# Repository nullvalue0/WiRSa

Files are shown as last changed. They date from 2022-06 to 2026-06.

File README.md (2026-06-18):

# RetroDisks WiRSa v3 - WiFi RS232 Serial Modem Adapter

The WiRSa v3 is a WiFi-to-RS232 serial adapter designed for legacy computing systems. It allows vintage computers to connect to modern networks via WiFi, supporting telnet BBS connectivity, file transfers, and network gateway functionality.



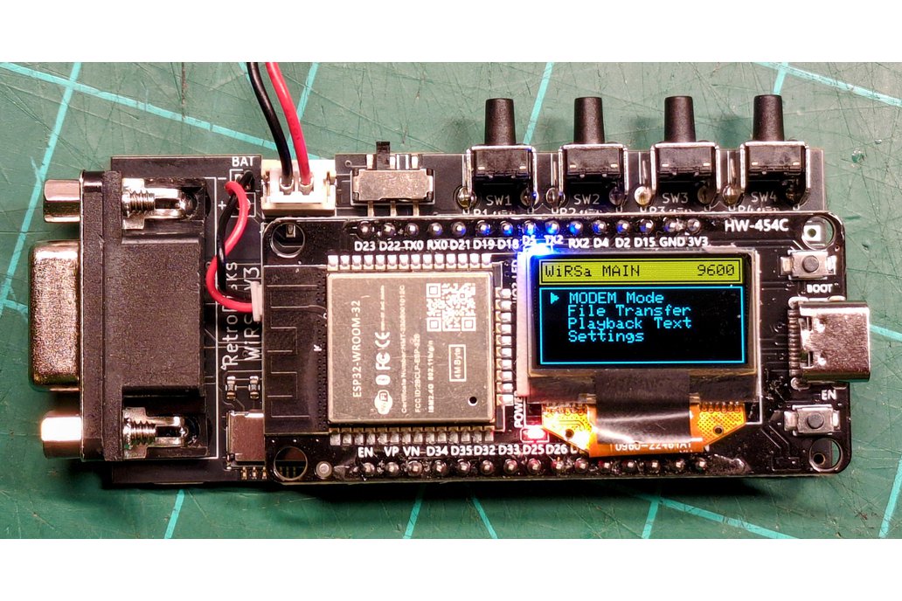
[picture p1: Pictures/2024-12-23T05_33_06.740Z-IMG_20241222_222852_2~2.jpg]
WiRSa Menu Action


## Kits & assembled units available for sale
If you prefer to save yourself some time, I have some units (fully assembled or kit) available for sale. I had quite a few PCB's made up and I am trying to keep these as cheap as possible. You can purchase on [SmallRun](https://smallrun.net/shop/retrodisks/wirsa-v3-wifi-rs232-serial-modem).
WiRSa v3 Wifi RS232 Serial Modem with SD Reader, SLIP, PPP, Telnet on SmallRun (https://smallrun.net/shop/retrodisks/wirsa-v3-wifi-rs232-serial-modem?ref=card)

## Features

### Hardware

- **Processor:** ESP-WROOM-32D with WiFi and Bluetooth 4.2 BLE
- **Display:** 128x64 two-color OLED display for settings, commands, and real-time data
- **Serial Port:** Female DB9 (DE9) connector
- **Full RS232 Breakout:**
  - DSR/DTR (Data Set Ready / Data Terminal Ready)
  - RTS/CTS (Request to Send / Clear to Send)
  - DCD (Data Carrier Detect)
  - RI (Ring Indicator)
- **Storage:** Built-in micro SD card reader for file transfers and text playback
- **Power:**
  - USB-C power connector
  - Optional 2000mAh 3.7V Li-Po battery (~14 hours runtime)
- **Navigation:** Four physical buttons for menu navigation

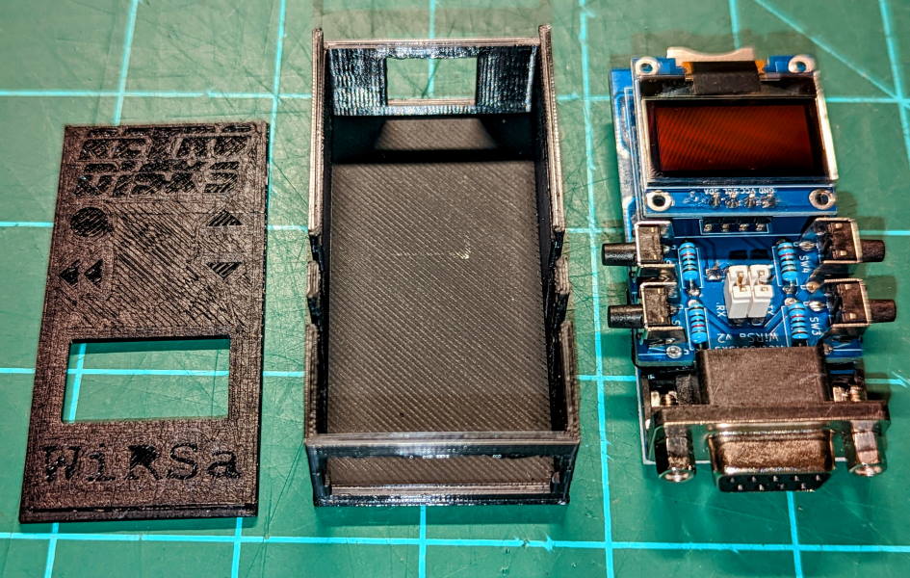
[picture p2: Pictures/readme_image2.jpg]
WiRSa Unboxing Action


### Operating Modes

1. **MODEM Mode** - Hayes-compatible AT command modem emulation for telnet/BBS connectivity
2. **Telnet Server** - Built-in telnet server allows for remote terminal access
3. **File Transfer** - Binary file transfer directly from SD card via XModem, YModem, and ZModem protocols
4. **Text Playback** - Display text files from SD card through the serial port
5. **PPP Gateway** - Point-to-Point Protocol gateway for TCP/IP networking
6. **SLIP Gateway** - Serial Line Internet Protocol gateway
7. **Utilities** - Diagnostics and troubleshooting tools including signal monitoring and loopback testing
8. **Config** - Settings for baud rate, serial configuration, display orientation, and more

### Software Features

- **AT Command Set** - Full Hayes-compatible modem commands
- **Web Interface** - Built-in web server for status monitoring, configuration and file management
- **Flow Control** - Hardware (RTS/CTS) and software (XON/XOFF) flow control
- **Speed Dial** - 10 programmable speed dial entries
- **PETSCII Translation** - Support for Commodore computers
- **Telnet Protocol** - Automatic Telnet IAC handling
- **OTA Updates** - Over-the-air firmware updates via HTTP

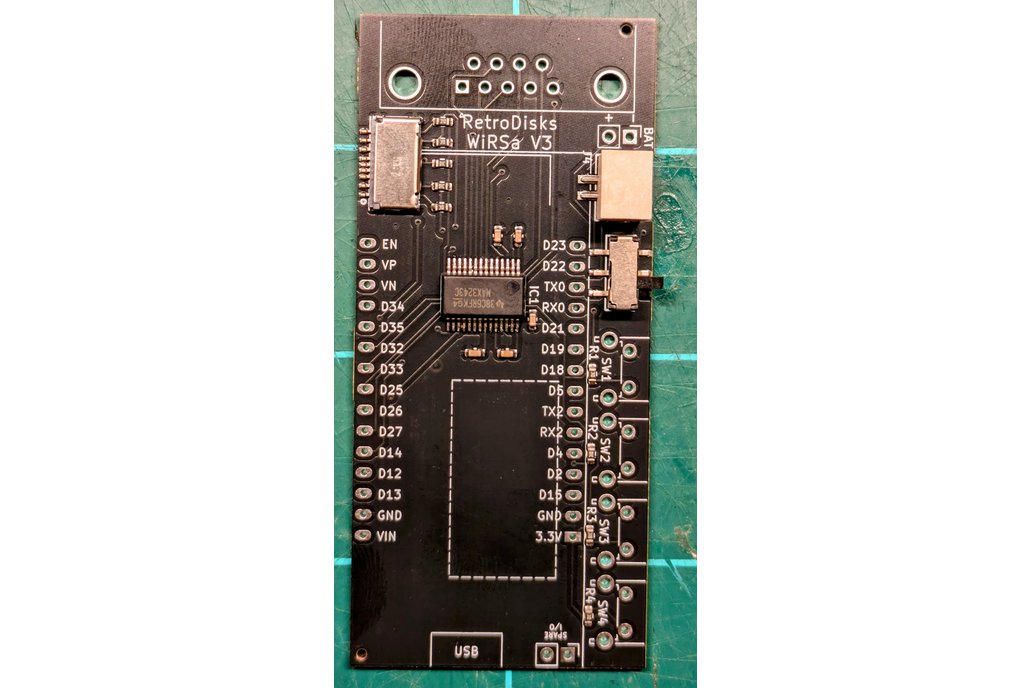
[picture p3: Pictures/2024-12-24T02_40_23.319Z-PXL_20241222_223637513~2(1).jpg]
WiRSa BBS Action


## Getting Started

### WiFi Configuration

1. Connect to your computer via serial port (default: 9600 baud, 8N1)
2. Enter your WiFi credentials using AT commands (2.4 GHz networks only):
   ```
   AT$SSID=YourNetworkName
   AT$PASS=YourPassword
   ```
3. Save settings: `AT&W`
4. Reboot or reconnect to apply

### Connecting to a BBS

Use the dial command with the host and port:
```
ATDT bbs.example.com:23
```

Or configure speed dial entries:
```
AT&Z0=bbs.example.com:23
ATDS0
```

### Useful AT Commands

| Command | Description |
|---|---|
| `AT` | Test connection (returns OK) |
| `ATDT<host:port>` | Dial/connect to TCP host |
| `ATDS<0-9>` | Speed dial entry |
| `ATH` | Hang up connection |
| `ATA` | Answer incoming connection |
| `ATO` | Return online from command mode |
| `+++` | Escape to command mode (during connection) |
| `ATE0/1` | Echo off/on |
| `ATV0/1` | Verbose results off/on |
| `ATI` | Display network info |
| `AT&V` | View current settings |
| `AT&W` | Save settings to EEPROM |
| `ATZ` | Load settings from EEPROM |
| `AT&F` | Restore factory defaults |
| `AT&K<0/1/2>` | Flow control (0=none, 1=hardware, 2=software) |
| `ATNET<0/1>` | Telnet protocol handling off/on |
| `ATPET=<0/1>` | PETSCII translation off/on |
| `AT$SSID=` | Set WiFi SSID |
| `AT$PASS=` | Set WiFi password |
| `AT$SP=<port>` | Set listening port |
| `ATS0=<0/1>` | Auto-answer off/on |
| `ATFC` | Check for firmware updates |
| `ATFU` | Perform firmware update |
| `AT?` or `ATHELP` | Display help |
| `ATX` | Exit MODEM Mode, return to WiRSa main menu |

## File Transfers

The WiRSa supports binary file transfers directly from the SD card using industry-standard protocols:

- **XModem** - Basic 128-byte block transfer with checksum
- **YModem** - Batch file transfer with filename and size
- **ZModem** - Streaming protocol with CRC16/CRC32 and automatic resume

To transfer files:
1. Insert SD card with files
2. Select "File Transfer" from the main menu
3. Choose the transfer protocol
4. Select send or receive
5. Initiate the transfer from your terminal software

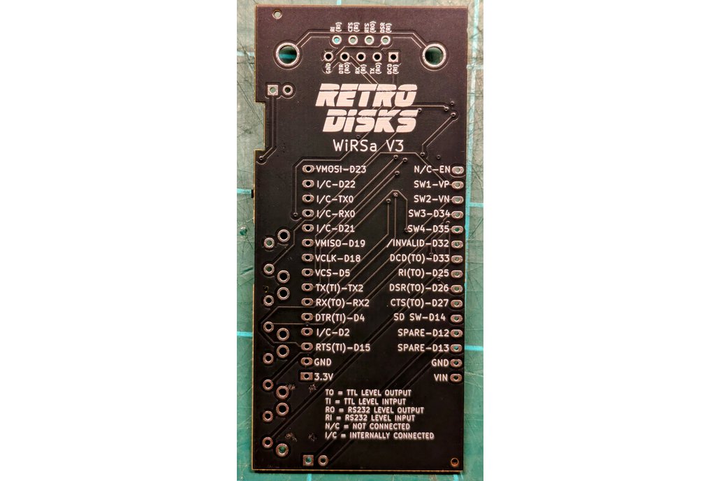
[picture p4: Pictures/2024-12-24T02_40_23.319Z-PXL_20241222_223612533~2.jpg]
WiRSa PCB Action


## SLIP / PPP Gateway Modes

The WiRSa provides full TCP/IP networking capabilities for vintage computers through two standard protocols: **SLIP** (Serial Line Internet Protocol) and **PPP** (Point-to-Point Protocol). These modes turn the WiRSa into a dial-up internet gateway, allowing retro systems to browse the web, use email clients, FTP, and access other network services.

### How It Works

Both modes operate as NAT (Network Address Translation) gateways:
1. The vintage computer connects via the serial port
2. The WiRSa performs NAT translation between the serial link and WiFi
3. Outbound traffic is routed to the internet via the ESP32's WiFi connection
4. The vintage computer appears to have full internet access

### SLIP Mode

SLIP is a simpler, older protocol with less overhead. It works well with:
- **DOS** with packet drivers (ETHERSLIP, SLIPPER, etc.)
- **Early Windows 3.x** with Trumpet Winsock
- **Classic Mac OS** with MacSLIP or InterSLIP
- **Linux** with `slattach`

**Default Configuration:**
- Gateway IP: 192.168.7.1 (WiRSa)
- Client IP: 192.168.7.2 (vintage computer)
- DNS: 8.8.8.8

### PPP Mode

PPP is more robust with built-in negotiation, authentication support, and error detection. It's the standard for:
- **Windows 95/98/ME** Dial-Up Networking
- **Windows 3.11** with Microsoft DUN
- **Mac OS 8/9** with PPP/Remote Access
- **Linux** with `pppd`

**Default Configuration:**
- Gateway IP: 192.168.8.1 (WiRSa)
- Client IP: 192.168.8.2 (assigned to client)
- Primary DNS: 8.8.8.8
- Secondary DNS: 8.8.4.4

### Entering SLIP/PPP Mode

**From the WiRSa Menu: (*if your host OS is expecting an "always on" connection*)**
1. Navigate to "PPP Gateway" or "SLIP Gateway" from the main menu
2. Select "Start Gateway"

**Using AT Dial Commands: (*must set the device to Modem Mode first*)**
```
ATDT SLIP      - Enter SLIP mode
ATDT 7547      - Enter SLIP mode (phone keypad for "SLIP")

ATDT PPP       - Enter PPP mode
ATDT 777       - Enter PPP mode (phone keypad for "PPP")
```

**Using AT Commands: (*must set the device to Modem Mode first*)**
```
AT$SLIP        - Enter SLIP mode directly
AT$PPP         - Enter PPP mode directly
```

### Port Forwarding

Port forwarding allows incoming connections from the internet to reach services running on your vintage computer. This is useful for:

- **Hosting a BBS** - Run a BBS on your vintage computer accessible from the internet
- **FTP Server** - Share files from your retro machine
- **Web Server** - Host a vintage web server (Windows 95 Personal Web Server, etc.)
- **Game Servers** - Host multiplayer games on classic systems
- **SSH/Telnet Access** - Remote into your vintage computer

**Configuring Port Forwards:**

From the menu:
1. Enter SLIP or PPP Gateway menu
2. Select "Port Forwards"
3. Choose "Add Forward"
4. Enter protocol (TCP/UDP), external port, internal IP, and internal port

Using AT commands:
```
AT$SLIPFWD=TCP,80,80      - Forward TCP port 80 to client port 80
AT$SLIPFWD=UDP,53,53      - Forward UDP port 53 (DNS)
AT$SLIPFWDDEL=0           - Remove forward at index 0

AT$PPPFWD=TCP,23,23       - Forward TCP port 23 (telnet)
AT$PPPFWD=TCP,21,21       - Forward TCP port 21 (FTP)
AT$PPPFWDDEL=0            - Remove forward at index 0
```

**Note:** Port forwards are shared between SLIP and PPP modes and persist across reboots.

### Setting Up SLIP Under DOS

**Requirements:**
- MS-DOS, DR-DOS, FreeDOS, etc
- A SLIP packet driver (ETHERSLIP, SLIPPER, or CSLIPPER)
- TCP/IP applications (mTCP suite, Arachne or MicroWeb browser, NCSA Telnet, etc.)

**Step 1: Configure WiRSa**
```
AT$SSID=YourWiFiNetwork
AT$PASS=YourPassword
AT&W
```

**Step 2: Install Packet Driver**

Create a batch file (e.g., `SLIP.BAT`):
```batch
@echo off
REM Load SLIP packet driver on COM1 at 115200 baud
ETHERSL 0x60 4 0x3F8 115200
REM Or for COM2: ETHERSL 0x60 3 0x2F8 115200
```

**Step 3: Configure TCP/IP Stack**

For mTCP, create `MTCP.CFG`:
```
PACKETINT 0x60
IPADDR 192.168.7.2
NETMASK 255.255.255.0
GATEWAY 192.168.7.1
NAMESERVER 8.8.8.8
```

Set environment variable:
```batch
SET MTCPCFG=C:\MTCP\MTCP.CFG
```

**Step 4: Connect**

On the WiRSa, start SLIP Gateway by enabling from the buttons/screen menu, from the serial menu (exit terminal after Starting Gateway, it starts immediately), or by dialing
```
ATDT SLIP
```

**Step 5: Test Connection**
```
PING 8.8.8.8
TELNET bbs.example.com
```

### Setting Up PPP Under Windows 95/98 Dial-Up Networking

**Step 1: Create a New Connection**
1. Open "My Computer" → "Dial-Up Networking"
2. Click "Make New Connection"
3. Name it "WiRSa Internet" (or any name)
4. Select your serial port modem (or "Standard Modem" on the COM port)
5. For phone number, enter: `PPP` (or `777`)

**Step 2: Configure the Connection**
1. Right-click the new connection → "Properties"
2. **General tab:** Ensure correct modem/port is selected
3. **Server Types tab:**
   - Type of Dial-Up Server: "PPP: Internet, Windows NT Server, Windows 98"
   - Uncheck "Log on to network" (unless needed)
   - Check "Enable software compression" (optional)
   - Check "TCP/IP" under Allowed network protocols
   - Uncheck NetBEUI and IPX/SPX unless needed
4. Click "TCP/IP Settings":
   - Select "Server assigned IP address"
   - Select "Server assigned name server addresses"
   - Click OK

**Step 3: Modem Settings**
1. Go to Control Panel → Modems → Properties
2. Set maximum speed to match WiRSa baud rate (115200 recommended, plus Flow Control enabled [AT&K1])
3. Under "Connection" tab, set 8 data bits, No parity, 1 stop bit
4. Make sure to put the WiRSa into Modem mode before proceeding

**Step 4: Connect**
1. Double-click the connection
2. Leave username/password blank (or enter any values - WiRSa ignores auth)
3. Click "Connect"
4. The WiRSa will respond "CONNECT PPP" and negotiate the link

**Step 5: Verify Connection**
- Open a command prompt: `ping 8.8.8.8`
- Open Internet Explorer and browse!

### Setting Up PPP Under Windows 3.11

**Requirements:**
- Windows 3.11 for Workgroups
- Microsoft TCP/IP-32 or Trumpet Winsock
- Dial-Up Networking 1.0 for Windows 3.11

**Step 1: Install TCP/IP-32**
1. Run Network Setup
2. Add "Microsoft TCP/IP-32"
3. Configure with DHCP or manual IP (the WiRSa will assign IPs)

**Step 2: Configure RAS (Remote Access Service)**
1. Install RAS if not present
2. Add your modem on the appropriate COM port
3. Create a new phonebook entry with phone number "PPP" or "777"

**Step 3: Connect**
1. Open Remote Access
2. Select your WiRSa entry
3. Make sure WiRSa is in Modem Mode
4. Click "Dial"

### Setting Up SLIP Under Linux

Linux has built-in SLIP support via the `slattach` utility. This guide covers configuring the serial port, enabling SLIP, and testing connectivity.

**Requirements:**
- Linux system with a physical serial port (directly connected to WiRSa)
- Root/sudo access
- `slattach` utility (usually included in `net-tools` or `slip` package)

**Step 1: Identify Your Serial Port**

First, identify the serial device. Physical serial ports are typically:
```bash
# First serial port (COM1 equivalent)
/dev/ttyS0

# Second serial port (COM2 equivalent)
/dev/ttyS1

# List available serial ports
ls -la /dev/ttyS*

# Check which serial ports are available
dmesg | grep -i ttyS
```

**Step 2: Configure the Serial Port**

Before starting SLIP, configure the serial port to match your WiRSa settings. Use `stty` to set the baud rate and other parameters:

```bash
# Set baud rate to 115200, 8N1, no flow control
sudo stty -F /dev/ttyS0 115200 cs8 -cstopb -parenb raw -echo

# For hardware flow control (if WiRSa has AT&K1 enabled), add crtscts:
sudo stty -F /dev/ttyS0 115200 cs8 -cstopb -parenb raw -echo crtscts

# Verify settings
stty -F /dev/ttyS0 -a
```

Key `stty` options:
| Option | Description |
|---|---|
| `115200` | Baud rate (match WiRSa setting) |
| `cs8` | 8 data bits |
| `-cstopb` | 1 stop bit (use `cstopb` for 2) |
| `-parenb` | No parity |
| `raw` | Raw mode (no input/output processing) |
| `-echo` | Disable local echo |
| `crtscts` | Enable hardware flow control |

**Step 3: Test Serial Communication**

Before enabling SLIP, verify you can communicate with the WiRSa:

```bash
# Open a simple terminal session
# Press Ctrl+C to exit when done
sudo cat /dev/ttyS0 &
echo "AT" | sudo tee /dev/ttyS0

# You should see "OK" response from WiRSa
# Kill the background cat process
kill %1

# Alternative: use screen or minicom
screen /dev/ttyS0 115200
# (Press Ctrl+A then K to exit screen)
```

**Step 4: Start SLIP Gateway on WiRSa**

From your terminal session with WiRSa, enter SLIP mode:
```
AT$SLIP
```
Or dial into SLIP mode:
```
ATDT SLIP
```

You should see "CONNECT SLIP" response. Now exit your terminal program (the serial port must be free for slattach).

**Step 5: Enable SLIP on Linux**

Attach the SLIP interface using `slattach`:

```bash
# Start slattach in the background
# -p slip = SLIP protocol
# -s 115200 = baud rate
sudo slattach -p slip -s 115200 /dev/ttyS0 &

# Note the PID for later cleanup
SLATTACH_PID=$!
```

**Step 6: Configure the Network Interface**

Once slattach is running, a `sl0` interface will be created. Configure it:

```bash
# Bring up the interface with the client IP
sudo ifconfig sl0 192.168.7.2 pointopoint 192.168.7.1 up

# Or using ip command (modern systems)
sudo ip addr add 192.168.7.2 peer 192.168.7.1 dev sl0
sudo ip link set sl0 up

# Add default route through the SLIP gateway (optional - routes all traffic through WiRSa)
sudo ip route add default via 192.168.7.1 dev sl0

# Or add only specific routes
sudo ip route add 8.8.8.8 via 192.168.7.1 dev sl0
```

**Step 7: Configure DNS**

Add the DNS server to your resolver configuration:

```bash
# Temporary - add to /etc/resolv.conf
echo "nameserver 8.8.8.8" | sudo tee -a /etc/resolv.conf

# For systems using systemd-resolved
sudo resolvectl dns sl0 8.8.8.8
```

**Step 8: Test the Connection**

Verify connectivity through the SLIP link:

```bash
# Ping the WiRSa gateway
ping -c 3 192.168.7.1

# Ping an external IP (Google DNS)
ping -c 3 8.8.8.8

# Test DNS resolution
ping -c 3 google.com

# Check routing
ip route show
```

Expected output for successful ping:
```
PING 192.168.7.1 (192.168.7.1) 56(84) bytes of data.
64 bytes from 192.168.7.1: icmp_seq=1 ttl=64 time=5.23 ms
64 bytes from 192.168.7.1: icmp_seq=2 ttl=64 time=4.89 ms
64 bytes from 192.168.7.1: icmp_seq=3 ttl=64 time=5.01 ms
```

**Step 9: Cleanup (When Done)**

To disconnect and clean up:

```bash
# Bring down the interface
sudo ip link set sl0 down

# Kill slattach
sudo kill $SLATTACH_PID
# Or find and kill by name
sudo killall slattach
```

**Complete Setup Script**

Here's a complete script to automate the Linux SLIP setup:

```bash
#!/bin/bash
# slip-connect.sh - Connect to WiRSa via SLIP

DEVICE="/dev/ttyS0"
BAUD="115200"
LOCAL_IP="192.168.7.2"
GATEWAY_IP="192.168.7.1"
DNS="8.8.8.8"

# Configure serial port
sudo stty -F $DEVICE $BAUD cs8 -cstopb -parenb raw -echo

# Start slattach
sudo slattach -p slip -s $BAUD $DEVICE &
sleep 2

# Configure interface
sudo ip addr add $LOCAL_IP peer $GATEWAY_IP dev sl0
sudo ip link set sl0 up

# Add route for external traffic
sudo ip route add default via $GATEWAY_IP dev sl0

# Configure DNS
sudo resolvectl dns sl0 $DNS 2>/dev/null || echo "nameserver $DNS" | sudo tee /etc/resolv.conf

echo "SLIP connection established"
echo "  Local IP:  $LOCAL_IP"
echo "  Gateway:   $GATEWAY_IP"
echo "  DNS:       $DNS"
echo ""
echo "Test with: ping 8.8.8.8"
```

**Troubleshooting**

| Issue | Solution |
|---|---|
| "Device or resource busy" | Another program is using the serial port. Close any terminal emulators. |
| No sl0 interface appears | Check if slattach is running: `ps aux \| grep slattach`. Verify WiRSa is in SLIP mode. |
| Ping to gateway fails | Verify serial settings match WiRSa. Check cable connections. |
| External pings fail | Ensure WiRSa has WiFi connectivity. Check `AT$SLIPSTAT` for packet statistics. |
| Permission denied | Use sudo or add your user to the `dialout` group: `sudo usermod -aG dialout $USER` |
| Serial port not found | Ensure the serial port is enabled in BIOS/UEFI. Check `setserial -g /dev/ttyS*` for port status. |

### Configuration AT Commands

**SLIP Configuration:**
| Command | Description |
|---|---|
| `AT$SLIP` | Enter SLIP gateway mode |
| `AT$SLIPIP=x.x.x.x` | Set gateway IP address |
| `AT$SLIPCLIENT=x.x.x.x` | Set client IP address |
| `AT$SLIPDNS=x.x.x.x` | Set DNS server |
| `AT$SLIPSHOW` | Show current SLIP configuration |
| `AT$SLIPSTAT` | Show SLIP statistics |
| `AT$SLIPFWD=proto,ext,int` | Add port forward |
| `AT$SLIPFWDDEL=index` | Remove port forward |

**PPP Configuration:**
| Command | Description |
|---|---|
| `AT$PPP` | Enter PPP gateway mode |
| `AT$PPPGW=x.x.x.x` | Set gateway IP address |
| `AT$PPPPOOL=x.x.x.x` | Set client pool start IP |
| `AT$PPPDNS=x.x.x.x` | Set primary DNS server |
| `AT$PPPDNS2=x.x.x.x` | Set secondary DNS server |
| `AT$PPPSHOW` | Show current PPP configuration |
| `AT$PPPSTAT` | Show PPP statistics |
| `AT$PPPFWD=proto,ext,int` | Add port forward |
| `AT$PPPFWDDEL=index` | Remove port forward |
| `AT$PPPFWDLIST` | List all port forwards |

### Exiting SLIP/PPP Mode

- Press the **BACK button** on the WiRSa
- Send `+++` escape sequence (USB serial only in SLIP mode)
- Disconnect from the client side (PPP will detect link termination)

## Telnet Server Mode

The WiRSa includes a built-in Telnet server that allows remote access to devices connected via the serial port. This is useful for:

- **Vintage terminals and computers** - Access systems that originally connected to serial terminals (mainframes, minicomputers, Unix systems)
- **Serial console access** - Remotely manage routers, switches, or embedded devices with serial management ports
- **Headless systems** - Access single-board computers or systems without displays
- **BBS hosting** - Run a BBS on a vintage computer and accept telnet connections

### How It Works

1. The WiRSa listens for incoming TCP connections on a configurable port (default: 23)
2. When a connection is made, data is bridged bidirectionally between the telnet client and the serial port
3. The remote user interacts with whatever is connected to the WiRSa's serial port as if they were locally connected

### Configuration

**Set the listening port:**
```
AT$SP=23        - Set server port to 23 (default telnet port)
AT$SP=2323      - Use alternate port 2323
AT$SP?          - Query current port
```

**Configure auto-answer:**
```
ATS0=1          - Enable auto-answer (automatically connect incoming calls)
ATS0=0          - Disable auto-answer (ring and wait for manual answer)
ATS0?           - Query current setting
```

**Telnet protocol handling:**
```
ATNET1          - Enable telnet IAC sequence handling (recommended for telnet clients)
ATNET0          - Disable telnet handling (raw TCP mode)
ATNET?          - Query current setting
```

### Connecting to the WiRSa

From any computer on the same network:
```bash
telnet <wirsa-ip-address> 23
```

Or with a custom port:
```bash
telnet <wirsa-ip-address> 2323
```

### Console Mode vs Call Mode

The WiRSa supports two types of incoming connections:

**Console Connection (First Connection):**
- The first telnet connection becomes a "console" session
- Stays in AT command mode - you can type AT commands
- Use `ATDT <host:port>` to dial out to BBSes
- Full modem emulation available

**Call Connection (With Auto-Answer):**
- When `ATS0=1` is set, subsequent connections bridge directly to serial
- Data passes transparently between telnet and serial
- Use `+++` to escape back to command mode
- Use `ATH` to hang up

### Example: Remote Terminal Access

**Scenario:** You have a vintage Unix system with a serial console, and you want to access it remotely via telnet.

1. Connect the WiRSa to the Unix system's serial port
2. Configure WiRSa to match the system's serial settings:
   ```
   AT$SB=9600      - Set baud rate (match your system)
   ATS0=1          - Enable auto-answer
   ATNET1          - Enable telnet handling
   AT&W            - Save settings
   ```
3. From a remote computer, telnet to the WiRSa's IP address
4. You'll be connected directly to the Unix system's serial console

### Example: Hosting a BBS

**Scenario:** Run a BBS on a vintage computer and accept incoming telnet connections.

1. Connect WiRSa to the vintage computer running BBS software
2. Configure WiRSa:
   ```
   AT$SP=23        - Listen on port 23
   ATS0=1          - Auto-answer incoming connections
   ATNET1          - Handle telnet protocol
   AT&W            - Save settings
   ```
3. Configure your router to forward port 23 to the WiRSa's IP address
4. Users can now telnet to your public IP to access the BBS

### Manual Answer Mode

When auto-answer is disabled (`ATS0=0`), incoming connections trigger a "RING" message:

```
RING
RING
RING
```

To answer manually, type:
```
ATA             - Answer the incoming call
```

This is useful when you want to screen incoming connections or when the connected device needs preparation before accepting a connection.

## Diagnostics

The Utilities menu provides diagnostic tools for troubleshooting:

- **Signal Monitor** - Real-time display of RS232 signal states (DCD, RTS, CTS, DTR, DSR, RI)
- **Loopback Test** - Test serial communication integrity
- **Statistics** - View connection counts and byte transfer statistics

## Hardware Connections

### Pin Assignments

| Function | GPIO | Description |
|---|---|---|
| RXD2 | 16 | UART2 RX (from computer) |
| TXD2 | 17 | UART2 TX (to computer) |
| DCD | 33 | Data Carrier Detect (output) |
| RTS | 15 | Request to Send (output) |
| CTS | 27 | Clear to Send (input) |
| DTR | 4 | Data Terminal Ready |
| DSR | 26 | Data Set Ready |
| RI | 25 | Ring Indicator |
| SD CS | 5 | SD Card Chip Select |
| SD MOSI | 23 | SD Card MOSI |
| SD MISO | 19 | SD Card MISO |
| SD SCK | 18 | SD Card Clock |

### Navigation Buttons

| Button | GPIO | Function |
|---|---|---|
| SW1 | 36 | DOWN |
| SW2 | 39 | BACK |
| SW3 | 34 | ENTER |
| SW4 | 35 | UP |

## Building the Firmware

This is a PlatformIO project. See [README-PLATFORMIO.md](README-PLATFORMIO.md) for detailed build instructions.

Quick start:
```bash
# Build firmware
platformio run

# Upload to ESP32
platformio run --target upload

# Monitor serial output
platformio device monitor
```

## Origin Story

The WiRSa originated as a film prop for Apple TV's "The Shining Girls," where it simulated realistic computer interaction by playing back pre-recorded text files while actors typed on vintage terminals.

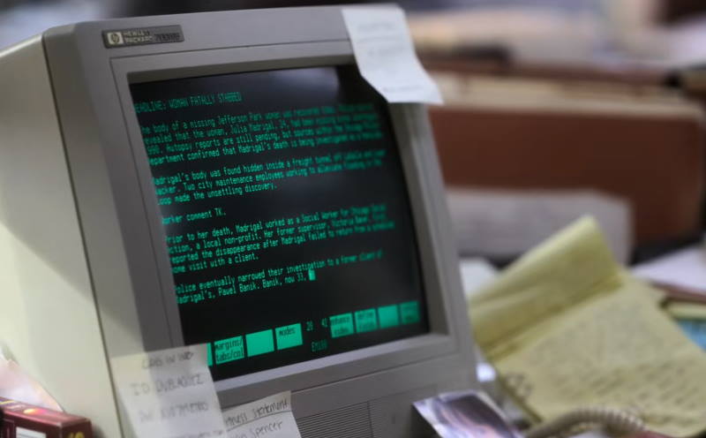
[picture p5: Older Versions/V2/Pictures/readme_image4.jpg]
WiRSa On Film


## Resources

- **Source Code:** Complete firmware, schematics (KiCAD), Gerber files, and enclosure designs (OpenSCAD) available in this repository
- **Contact:** nullvalue@gmail.com

## License

MIT License - See source code header for full license text.

Copyright (C) 2026 Aron Hoekstra

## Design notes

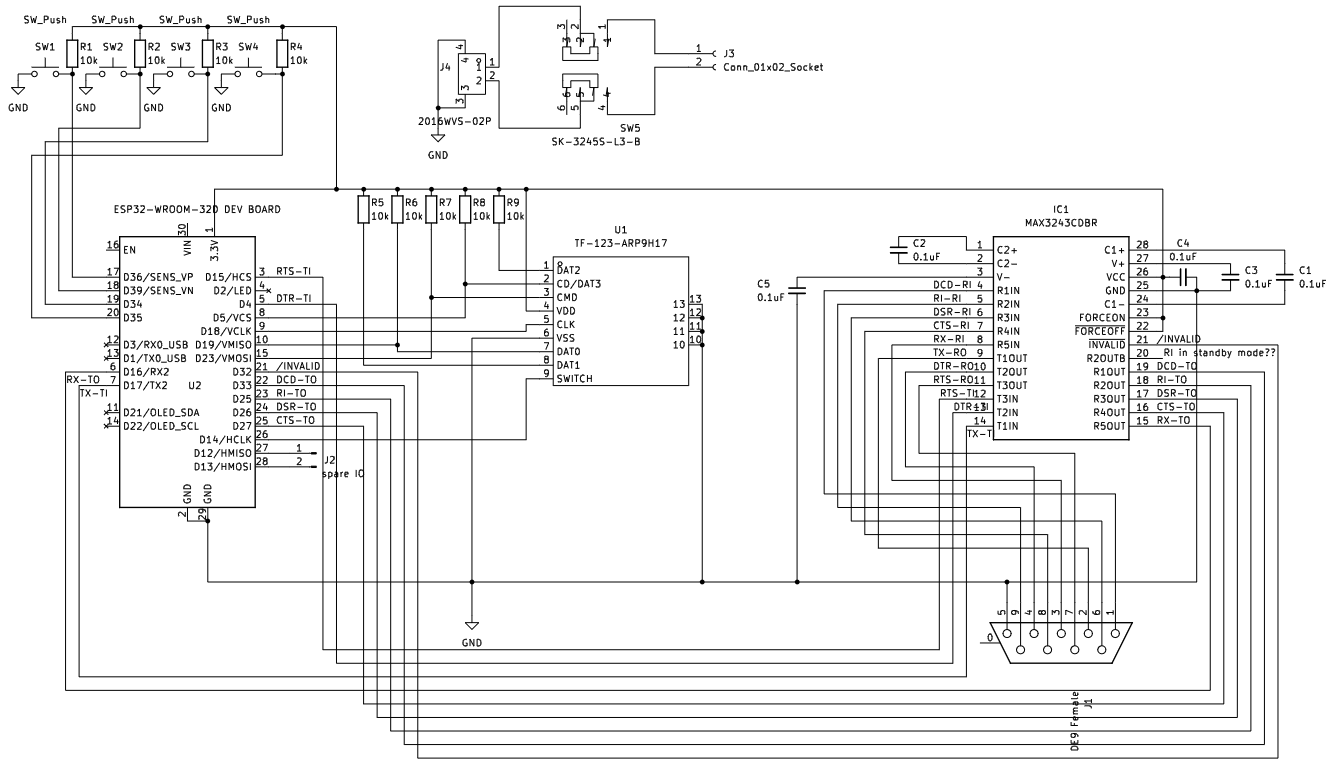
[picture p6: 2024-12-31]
PCB/WiRSa V3 Schematic.png

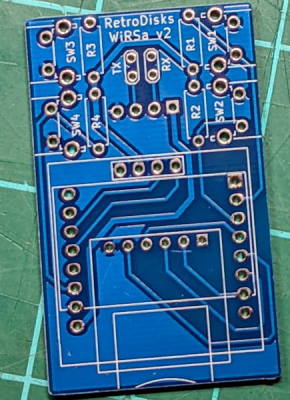
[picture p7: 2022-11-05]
Pictures/readme_image5.jpg

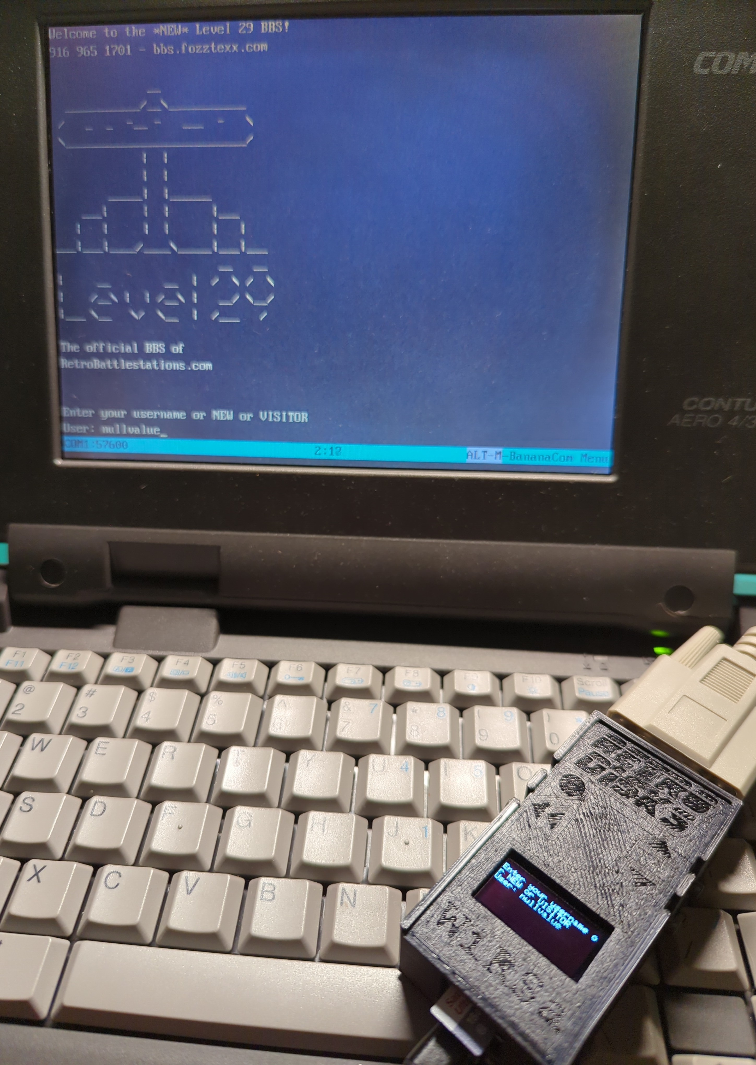
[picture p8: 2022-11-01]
Pictures/v2-IMG_20221031_160522~2 (6).jpg

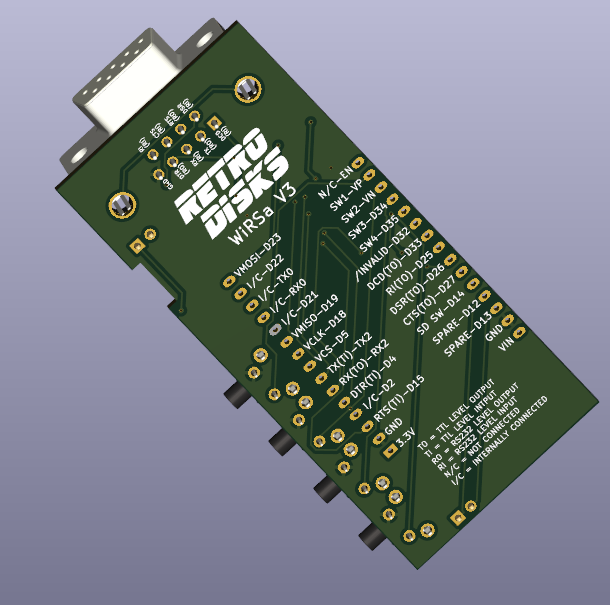
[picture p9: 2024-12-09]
Pictures/v3render1.png

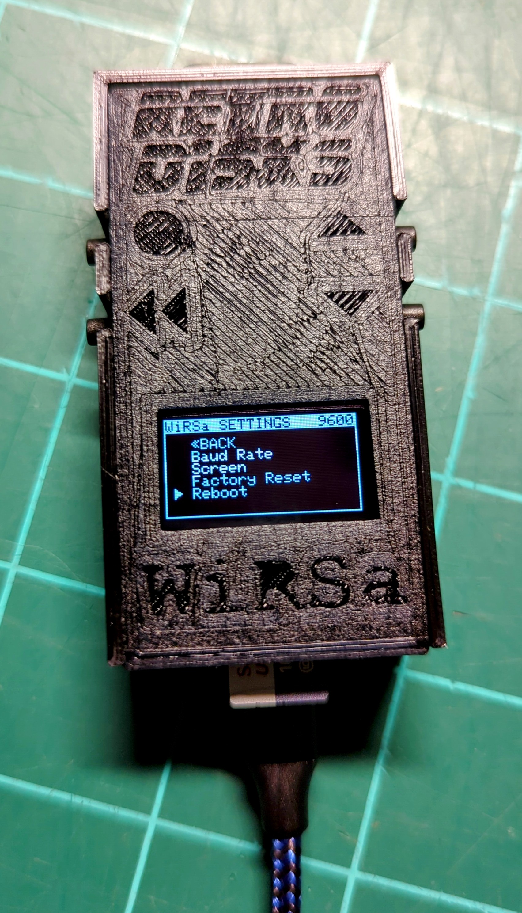
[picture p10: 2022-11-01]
Pictures/v2-IMG_20221031_160522~2 (2).jpg

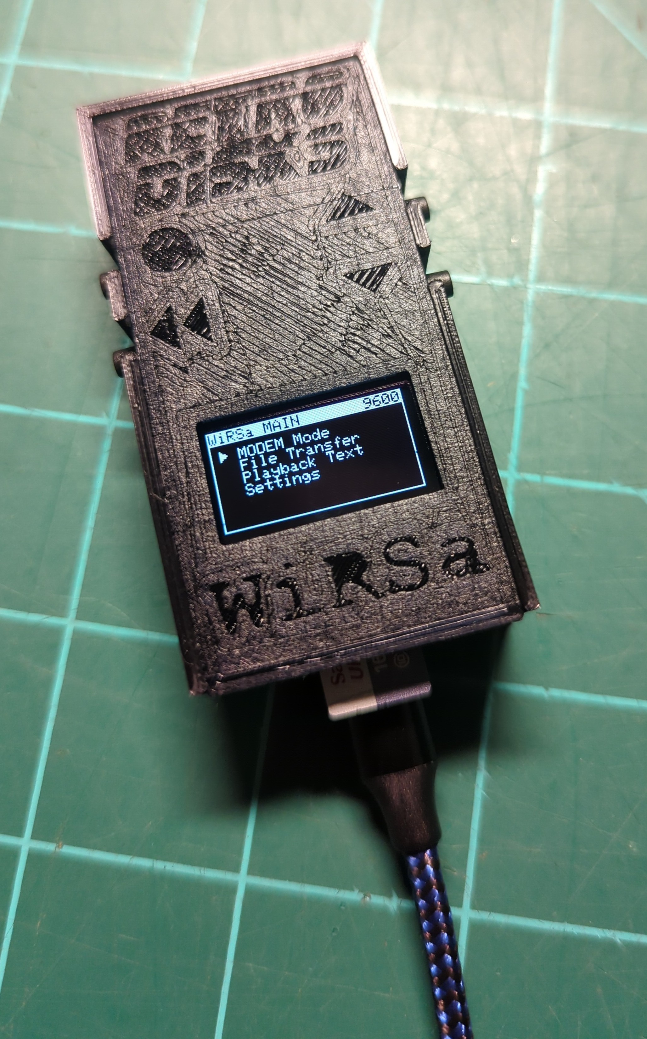
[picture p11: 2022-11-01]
Pictures/v2-IMG_20221031_160522~2 (1).jpg

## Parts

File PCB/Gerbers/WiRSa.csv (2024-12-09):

Comment | Designator | Footprint | LCSC
0.1uF | C1,C2,C3,C4,C5 | Capacitor_SMD:C_0603_1608Metric | C14663
MAX3243CDBR | IC1 | easyeda2kicad:SSOP-28_L10.2-W5.3-P0.65-LS7.8-BL | C414614
DE9 Female | J1 | Connector_Dsub:DSUB-9_Female_Horizontal_P2.77x2.84mm_EdgePinOffset4.94mm_Housed_MountingHolesOffset7.48mm
spare IO | J2 | Connector_PinHeader_2.54mm:PinHeader_1x02_P2.54mm_Vertical
Conn_01x02_Socket | J3 | Connector_PinHeader_2.54mm:PinHeader_1x02_P2.54mm_Vertical
2016WVS-02P | J4 | easyeda2kicad:CONN-SMD_P2.00_X2016WVS-02-9TSW | C5448068
10k | R1,R2,R3,R4,R5,R6,R7,R8,R9 | Resistor_SMD:R_0603_1608Metric | C25804
SW_Push | SW1,SW2,SW3,SW4 | Button_Switch_THT:SW_Tactile_SPST_Angled_PTS645Vx58-2LFS
SK-3245S-L3-B | SW5 | easyeda2kicad:SW-SMD_SK-3245S-L3-B | C405954
TF-123-ARP9H17 | U1 | easyeda2kicad:TF-SMD_TF-123-ARP9H15 | C2982548
ESP32-WROOM-32D DEV BOARD | U2 | esp32:ESP32-C3-DevKitC-02

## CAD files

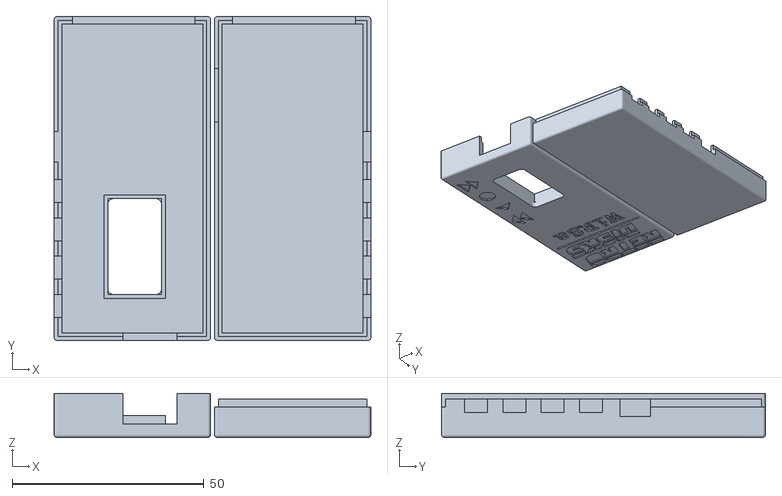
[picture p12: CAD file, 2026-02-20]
Enclosure/WiRSa Enclosure V3 No Battery.stl
82.6 x 84.5 x 11.5

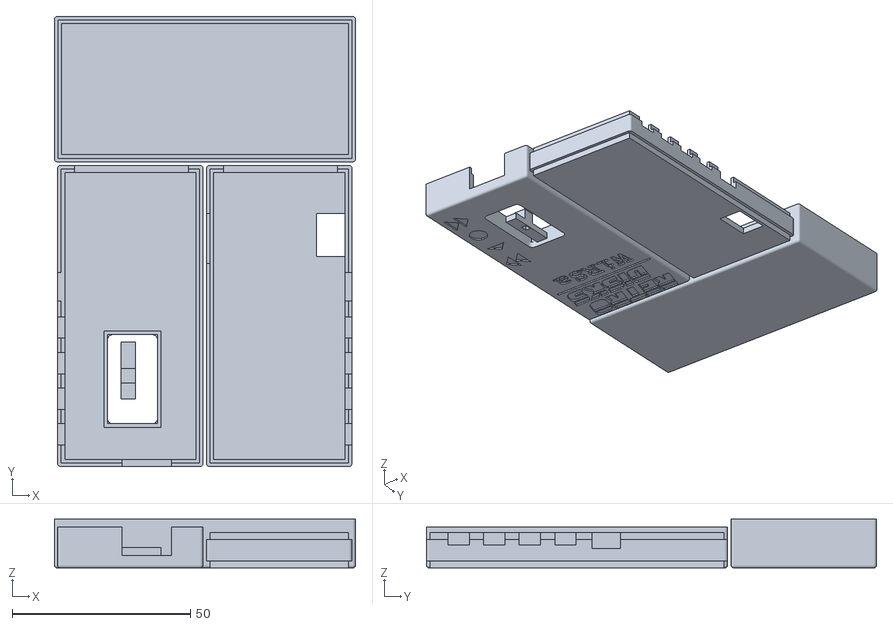
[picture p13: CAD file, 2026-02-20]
Enclosure/WiRSa Enclosure V3 With Battery.stl
84.5 x 126.3 x 13.8

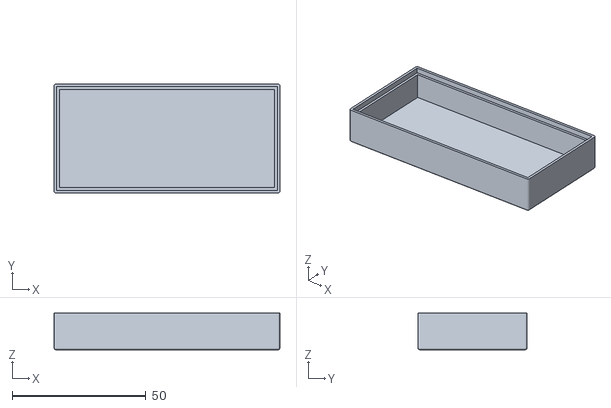
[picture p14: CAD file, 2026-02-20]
Enclosure/WiRSa Enclosure V3 Battery Only.stl
84.5 x 40.8 x 13.7

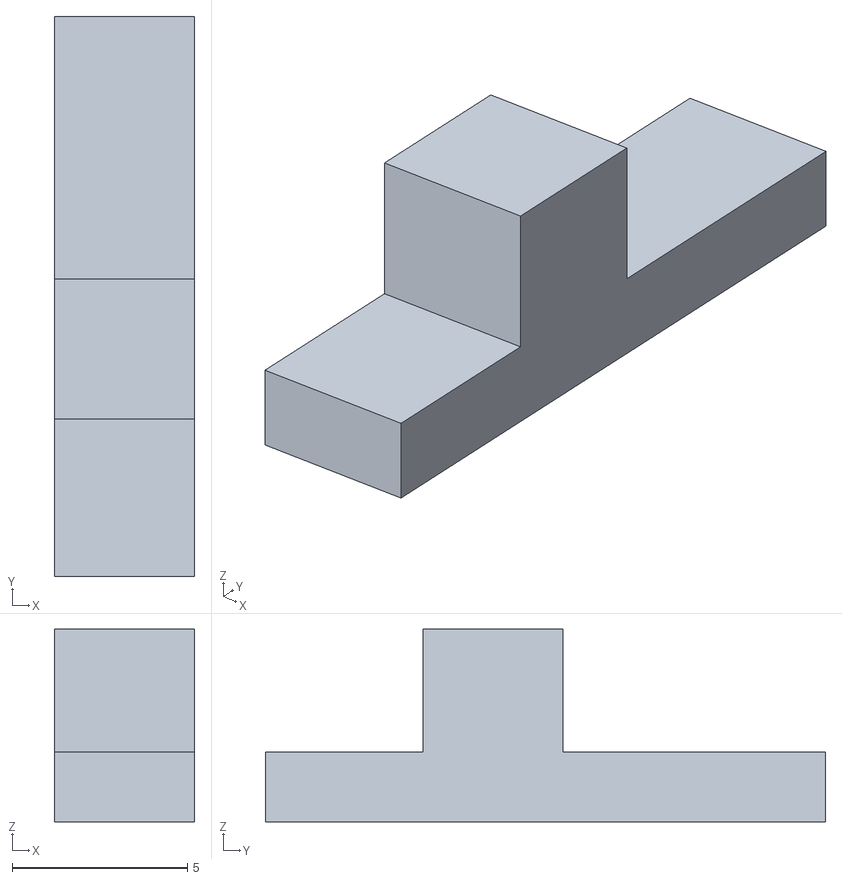
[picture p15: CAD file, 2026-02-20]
Enclosure/WiRSa Enclosure V3 Switch Only.stl
4.00 x 16.0 x 5.50

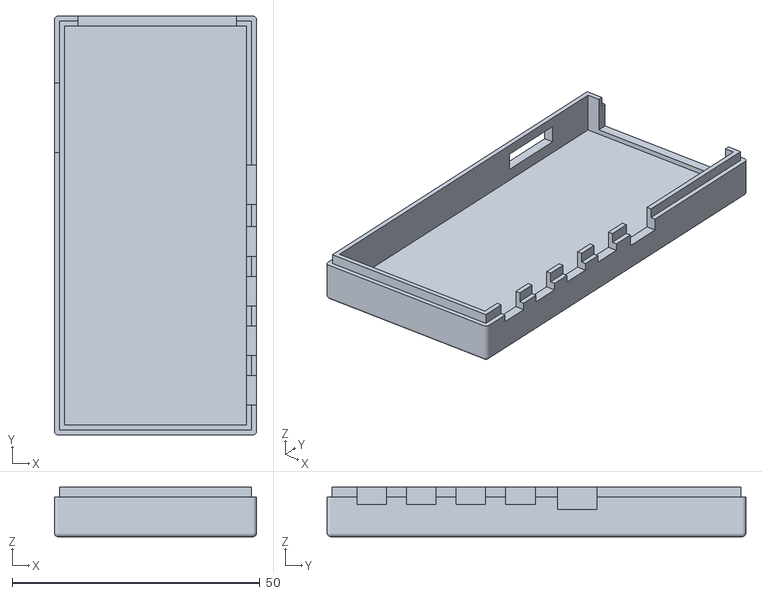
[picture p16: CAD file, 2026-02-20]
Enclosure/WiRSa Enclosure V3 Base Only NB.stl
40.8 x 84.5 x 10.00

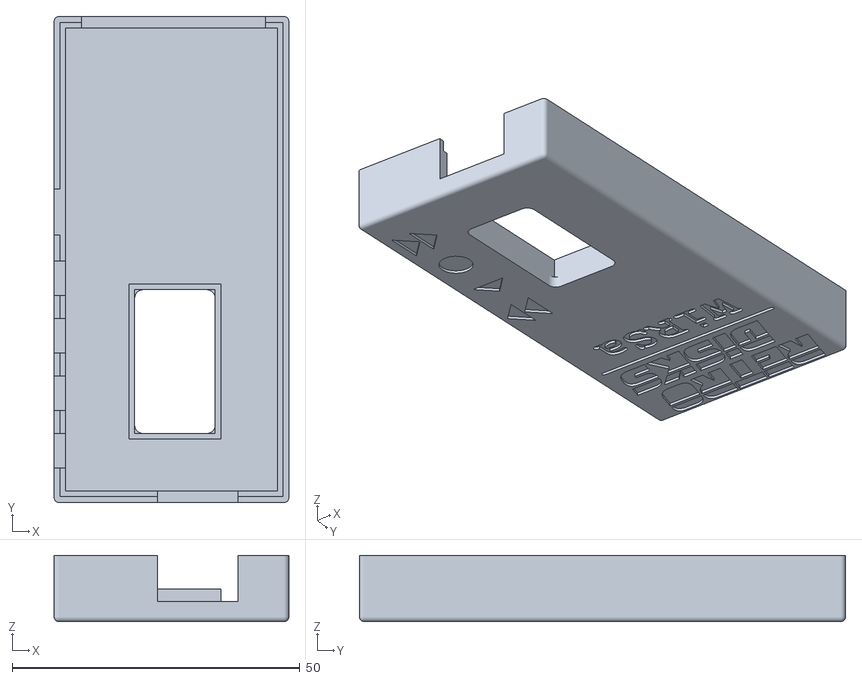
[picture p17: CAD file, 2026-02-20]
Enclosure/WiRSa Enclosure V3 Cover Only.stl
40.8 x 84.5 x 11.5

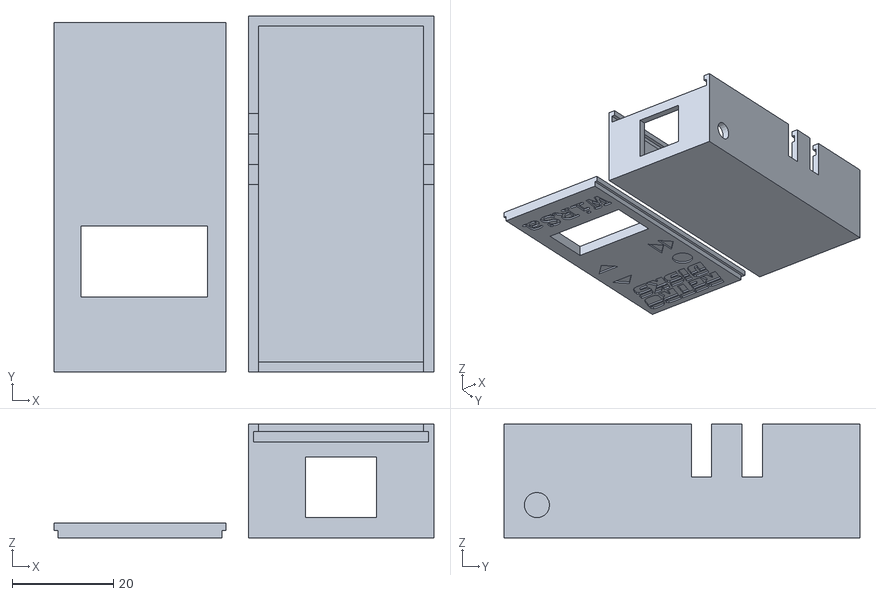
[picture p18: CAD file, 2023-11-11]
Enclosure/WiRSa Enclosure.stl
74.9 x 70.3 x 22.5

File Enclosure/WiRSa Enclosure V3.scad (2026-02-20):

render_base = true;
render_cover = true;
render_battery = true;
render_switch = true;

wall = 2.0;
width = 36.8; //37.6;
height = 6; //16;
length = 80.5; //82.8;

deviation = 0.5;
//$fn=20;
//$fs = 0.15;
$fn=60;
$fs = 0.01;

module cover(width, length, height, wall, deviation) {    
    difference() {
        union() {
            difference() {
                //cube([width + (2 * wall), length + (2 * wall), height + wall]);
                roundedcube([width + (2 * wall), length + (2 * wall), height + wall], false, .8, "zmin");
                translate([wall, wall, wall]) {
                    cube([width, length, height + 0.1]);
                }                
            }
            //snap fit bottom     
            translate([0, 0, height+wall]) {
                difference() {
                    //cube([width+(2*wall), length+(2*wall), 2]);
                    roundedcube([width+(2*wall), length+(2*wall), 2], false, .8, "z");
                    translate([1, 1, 0])
                        cube([width+(wall), length+(wall), 2]);
                }
            }            

            //display shroud
            shr_ht = 4.7;
            translate([13, 11, 1]) {
                cube([1,27,shr_ht]);
                cube([16,1,shr_ht]);
            }
            translate([28, 11, 1])
                cube([1,27,shr_ht]);
            translate([13, 37, 1])
                cube([16,1,shr_ht]);

        }
        
        //display opening
        translate([14, 12, 0]) {
            //cube([14,25,2]);
            roundedcube([14,25,2], false, 1.5, "z");
        }
        
        //power switch hole
        translate([0, wall+44.5, wall+7.5]) {
            cube([5,8,5]);
        }
              
        //SW1 Button Notch
        translate([0, wall+4, wall+5.5]) {
            cube([6,6,6],2.5,2.5);
        }
        //SW2 Button Notch
        translate([0, wall+14, wall+5.5]) {
            cube([6,6,6],2.5,2.5);
        }
        //SW3 Button Notch
        translate([0, wall+24, wall+5.5]) {
            cube([6,6,6],2.5,2.5);
        }
        //SW4 Button Notch
        translate([0, wall+34, wall+5.5]) {
            cube([6,6,6],2.5,2.5);
        }

        //serial port hole
        translate([wall+2.75, length, 2.5]) {
            cube(size=[32, 10, 10]);
        }
        
        //usb port
        translate([width+(wall*2)-14-8.8, 0, wall + 1.5])
            cube([14, 4, 8]);

        linear_extrude(.5) {
            translate([39,76,8]) //Retro
                rotate([0,0,0])
                    mirror([-1,0,0])
                        text("Retro", size=8, font="Retronoid:style=Italic");
            translate([35,67,8]) //Disks
                rotate([0,0,0])
                    mirror([-1,0,0])
                        text("D", size=8, font="Retronoid:style=Italic");
            translate([28,67,8]) //Disks
                rotate([0,0,0])
                    mirror([-1,0,0])
                        text("isks", size=8, font="Retronoid:style=Italic");
            
            translate([39.4,67,6]) //WiRSa
                rotate([0,0,0])
                    mirror([-1,0,0])
                        text("_________", size=5, font="Courier New:style=bold");


                translate([35,57,6]) //WiRSa
                    mirror([-1,0,0])
                        text("WiRSa", size=7, font="Courier New:style=bold");
            

                translate([11,wall+5,6]) //up
                        mirror([-1,0,0])
                            text("7", size=8, font="Webdings:style=bold");

                translate([11,wall+15,6]) //select
                        mirror([-1,0,0])
                            text("=", size=7.5, font="Webdings:style=bold");

                translate([11,wall+25,6])  //back
                        mirror([-1,0,0])
                            text("5", size=7.5, font="Webdings:style=bold");
                            
                translate([11,wall+35,6]) //down
                        mirror([-1,0,0])
                            text("8", size=8, font="Webdings:style=bold");
        }
        
    }
}


module base(width, length, height, wall, deviation) {
    difference() {
        union() {
            difference() {
                //cube([width + (2 * wall), length + (2 * wall), height + wall]);
                roundedcube([width + (2 * wall), length + (2 * wall), height + wall], false, .8, "zmin");
                translate([wall, wall, wall]) {
                    cube([width, length, height + 0.1]);
                }
                if (render_battery) {
                    cube([1,length+(wall*2),2]);
                    cube([width+(wall*2),1,2]);
                    translate([width+wall+1, 0, 0])
                        cube([1,length+(wall*2),2]);
                    translate([0,length+wall+1, 0])
                        cube([width+(wall*2),1,2]);
                    
                }
            }
            
            //snap fit top
            translate([1, 1, height+wall]) {
                difference() {
                    cube([width+wall, length+wall, 2]);
                translate([1, 1, 0])
                    cube([width, length, 2]);
                }
            }
        }
        
        if (render_battery) {
            //plug opening
            translate([width-6, 59, 0]) {
                cube([8,12,4]);
            } 
        }
        
        //sd card hole
        translate([0, wall+55, wall+2.5]) {
            cube([4,14,3.5]);
        }
        
        //power switch hole
        translate([width, wall+44.5, wall+3.5]) {
            cube([5,8,5]);
        }
        
        //SW1 Button Notch
        translate([width, wall+4, wall+4.5]) {
            cube([6,6,6],2.5,2.5);
        }
        //SW2 Button Notch
        translate([width, wall+14, wall+4.5]) {
            cube([6,6,6],2.5,2.5);
        }
        //SW3 Button Notch
        translate([width, wall+24, wall+4.5]) {
            cube([6,6,6],2.5,2.5);
        }
        //SW4 Button Notch
        translate([width, wall+34, wall+4.5]) {
            cube([6,6,6],2.5,2.5);
        }

        //serial port hole
        translate([wall+2.75, length, 3]) {
            cube(size=[32, 10, 10]);
        }
    }
}


module battery(width, length, height, wall, deviation) {
    
    difference() {
        union() {
            difference() {
                //cube([width + (2 * wall), length + (2 * wall), height + wall]);
                roundedcube([width + (2 * wall), length + (2 * wall), height + wall], false, .8, "zmin");
                translate([wall, wall, wall]) {
                    cube([width, length, height + 0.1]);
                }
            }
            //snap fit bottom     
            translate([0, 0, height+wall]) {
                difference() {
                    //cube([width+(2*wall), length+(2*wall), 2]);
                    roundedcube([width+(2*wall), length+(2*wall), 2], false, .8, "z");
                    translate([1, 1, 0])
                        cube([width+(wall), length+(wall), 2]);
                }
            }
        }
    }
}


module switch_cover() {
    difference() {
        cube([5.5,16,4]);
        
        translate([0,5.5,0.375])
            cube([3,2.25,1.75]);
        translate([2,0,0])
            cube([5,4.5,5]);
        translate([2,8.5,0])
            cube([5,8,5]);
    }
}

rot = 0;

if (render_base)
    base(width, length, height, wall, deviation);

if (render_cover)
    translate([-width-5,0,0])
        cover(width, length, height+1.5, wall, deviation);

if (render_battery)
    translate([width+5, length+5, 0])
        rotate([0,0,90])
            battery(width, length, height+3.75, wall, deviation);

if (render_switch)
    translate([-20, 19, 0])
        rotate([0,270,0])
            switch_cover();

module roundedcube(size = [1, 1, 1], center = false, radius = 0.5, apply_to = "all") {
	// If single value, convert to [x, y, z] vector
	size = (size[0] == undef) ? [size, size, size] : size;

	translate_min = radius;
	translate_xmax = size[0] - radius;
	translate_ymax = size[1] - radius;
	translate_zmax = size[2] - radius;

	diameter = radius * 2;

	obj_translate = (center == false) ?
		[0, 0, 0] : [
			-(size[0] / 2),
			-(size[1] / 2),
			-(size[2] / 2)
		];

	translate(v = obj_translate) {
		hull() {
			for (translate_x = [translate_min, translate_xmax]) {
				x_at = (translate_x == translate_min) ? "min" : "max";
				for (translate_y = [translate_min, translate_ymax]) {
					y_at = (translate_y == translate_min) ? "min" : "max";
					for (translate_z = [translate_min, translate_zmax]) {
						z_at = (translate_z == translate_min) ? "min" : "max";
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

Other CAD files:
Enclosure/WiRSa Enclosure V3 Base Only WB.stl
Older Versions/V2/Enclosure/WiRSa Enclosure.scad

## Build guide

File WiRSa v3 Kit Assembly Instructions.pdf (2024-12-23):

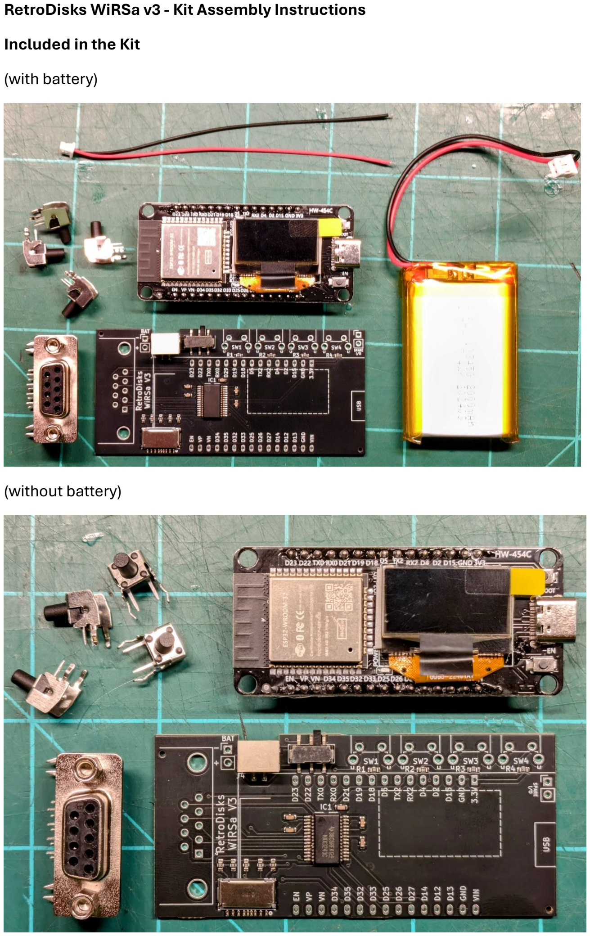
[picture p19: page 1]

RetroDisks WiRSa v3 - Kit Assembly Instructions Included in the Kit
(with battery)

(without battery)

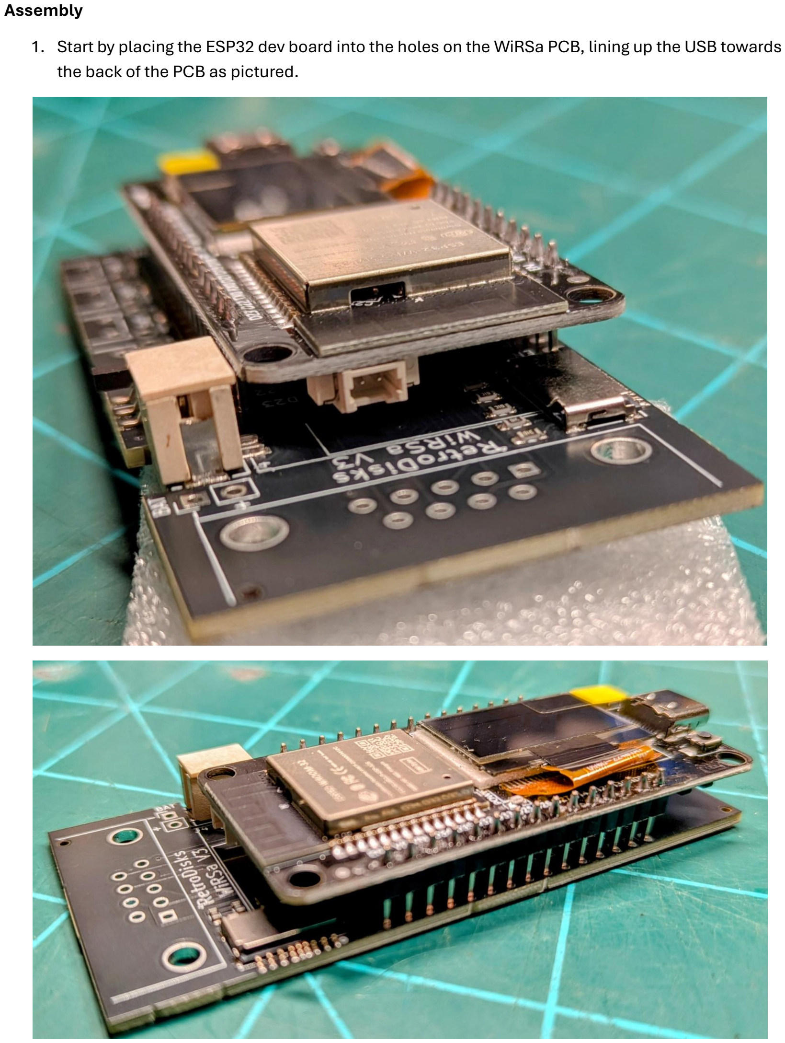
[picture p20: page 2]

Assembly
1. Start by placing the ESP32 dev board into the holes on the WiRSa PCB, lining up the USB towards the back of the PCB as pictured.

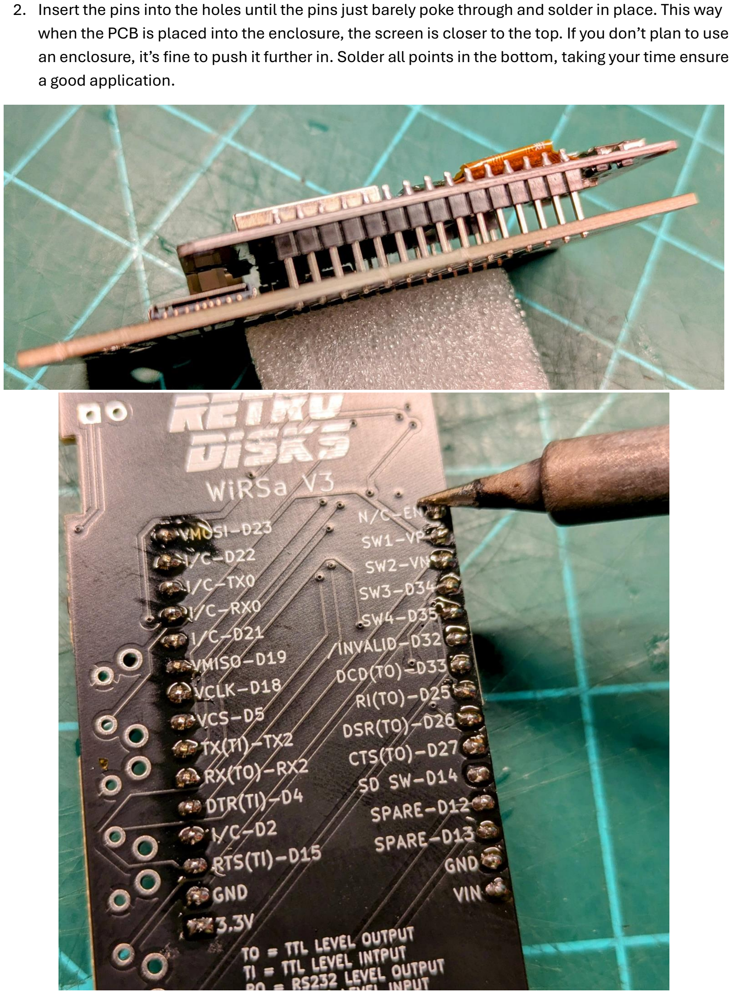
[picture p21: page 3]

2. Insert the pins into the holes until the pins just barely poke through and solder in place. This way when the PCB is placed into the enclosure, the screen is closer to the top. If you don’t plan to use an enclosure, it’s fine to push it further in. Solder all points in the bottom, taking your time ensure a good application.

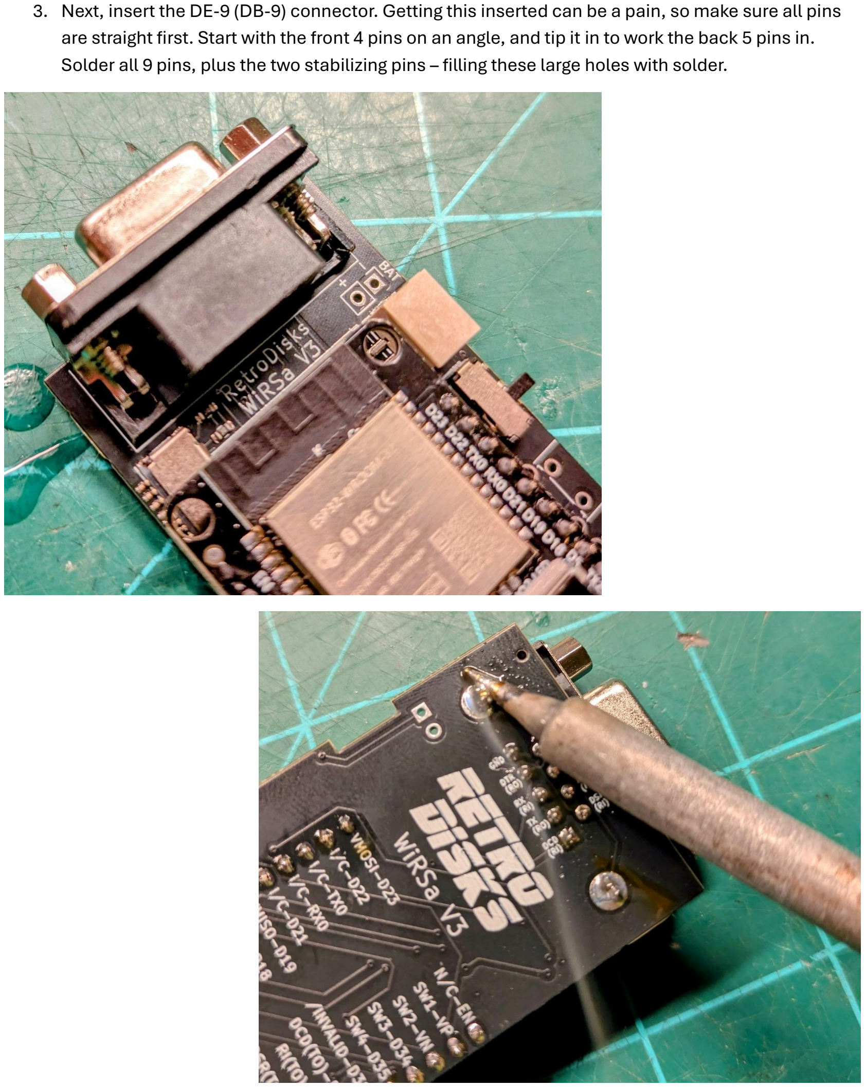
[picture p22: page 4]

3. Next, insert the DE-9 (DB-9) connector. Getting this inserted can be a pain, so make sure all pins are straight first. Start with the front 4 pins on an angle, and tip it in to work the back 5 pins in. Solder all 9 pins, plus the two stabilizing pins – filling these large holes with solder.

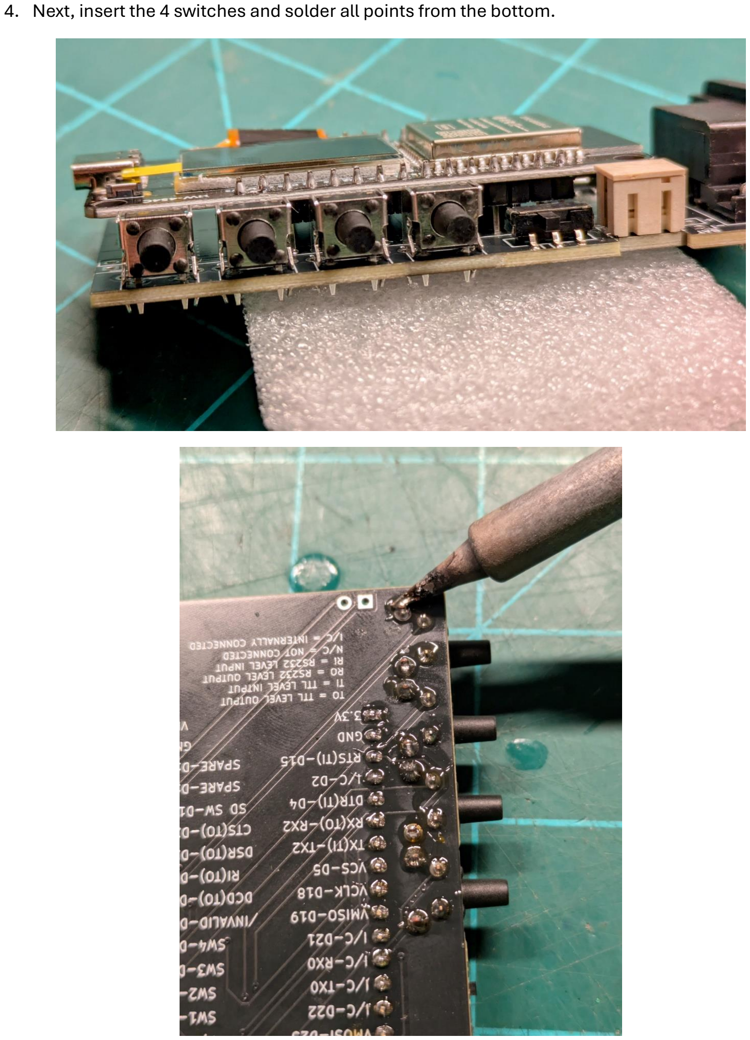
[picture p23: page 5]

4. Next, insert the 4 switches and solder all points from the bottom.

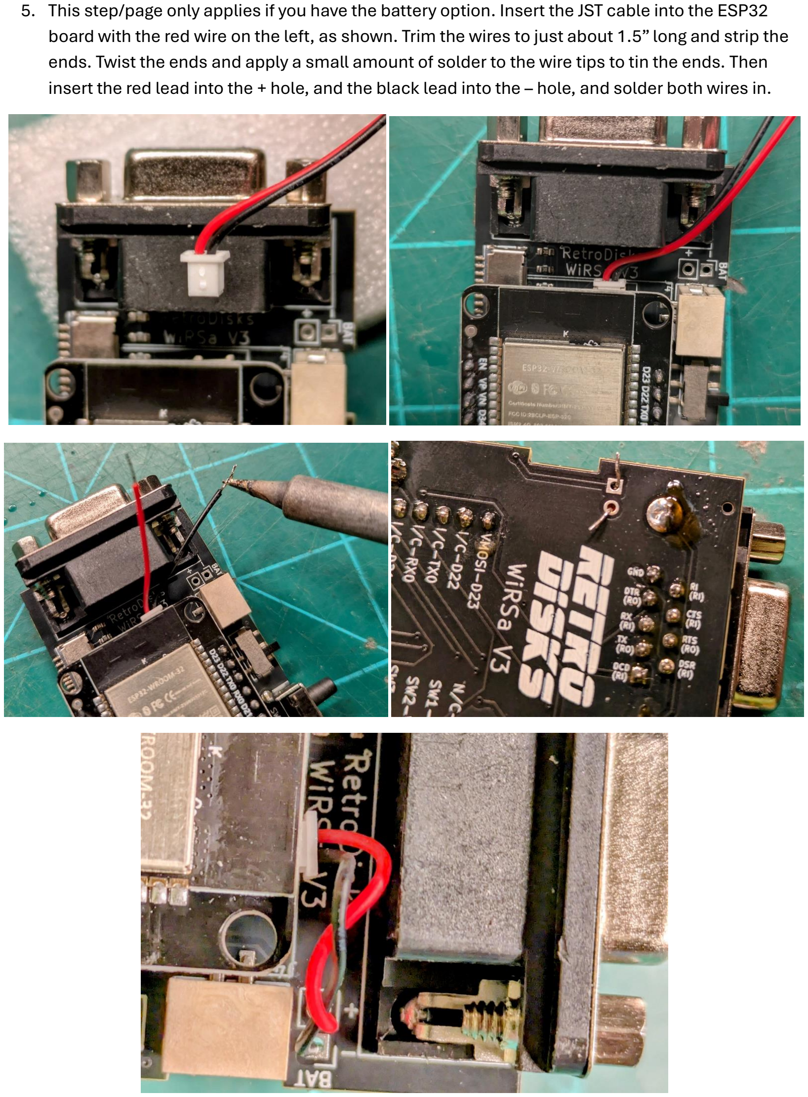
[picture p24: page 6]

5. This step/page only applies if you have the battery option. Insert the JST cable into the ESP32 board with the red wire on the left, as shown. Trim the wires to just about 1.5” long and strip the ends. Twist the ends and apply a small amount of solder to the wire tips to tin the ends. Then insert the red lead into the + hole, and the black lead into the – hole, and solder both wires in.

6. Then, especially if you plan on using an enclosure, trim the pins on the bottom of the PCB from the DE-9, switches and battery leads.

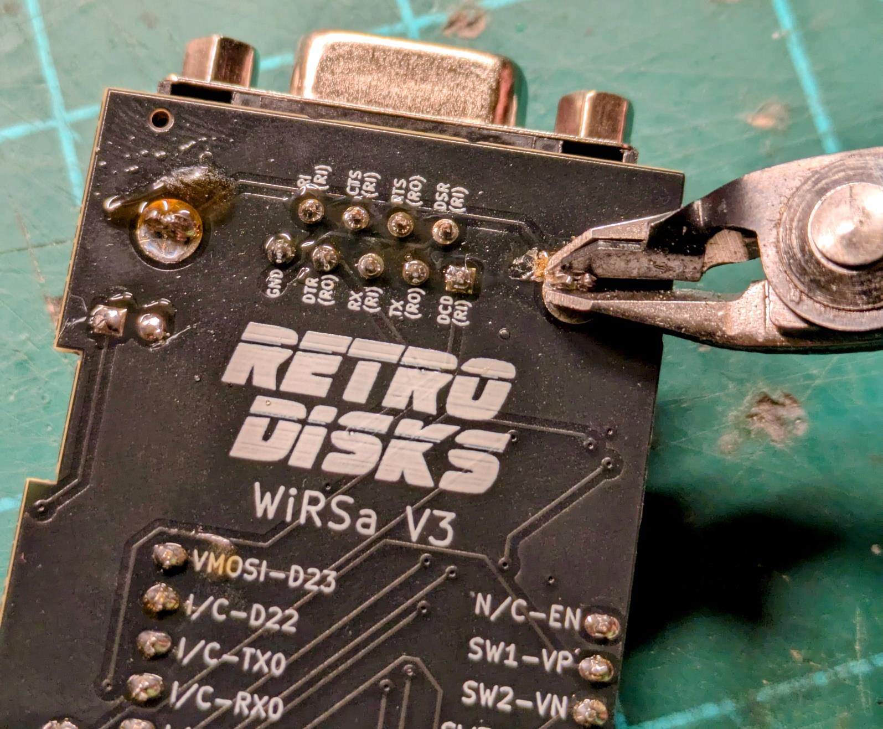
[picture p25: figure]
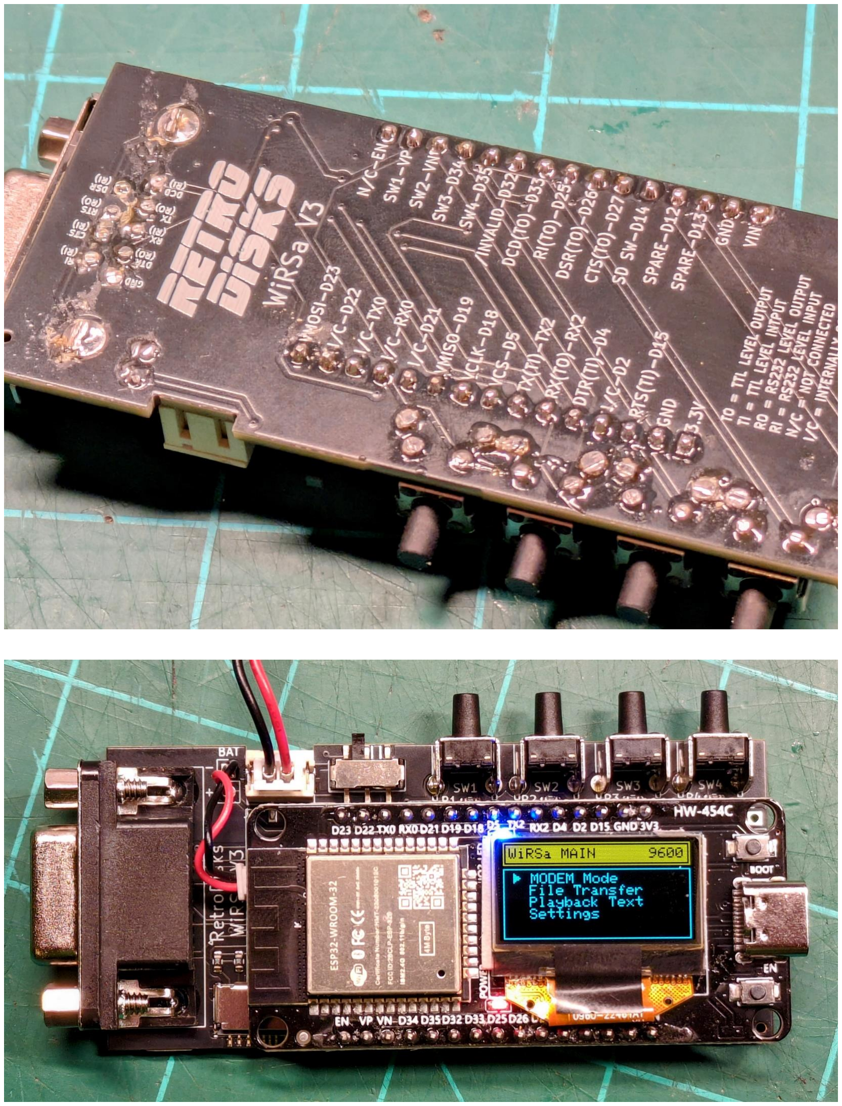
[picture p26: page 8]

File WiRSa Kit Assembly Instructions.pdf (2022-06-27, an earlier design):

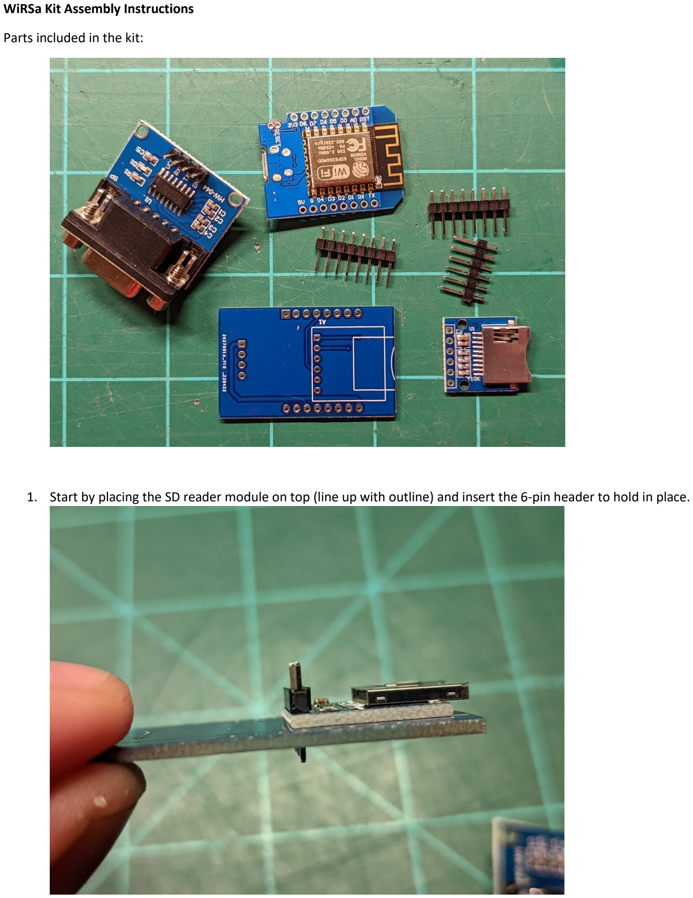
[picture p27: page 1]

WiRSa Kit Assembly Instructions

Parts included in the kit:

1. Start by placing the SD reader module on top (line up with outline) and insert the 6-pin header to hold in place.

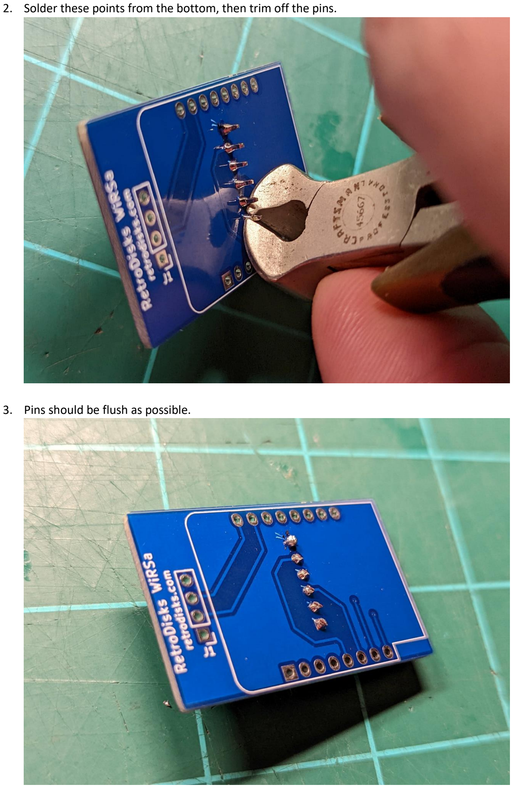
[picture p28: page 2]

2. Solder these points from the bottom, then trim off the pins.
3. Pins should be flush as possible.

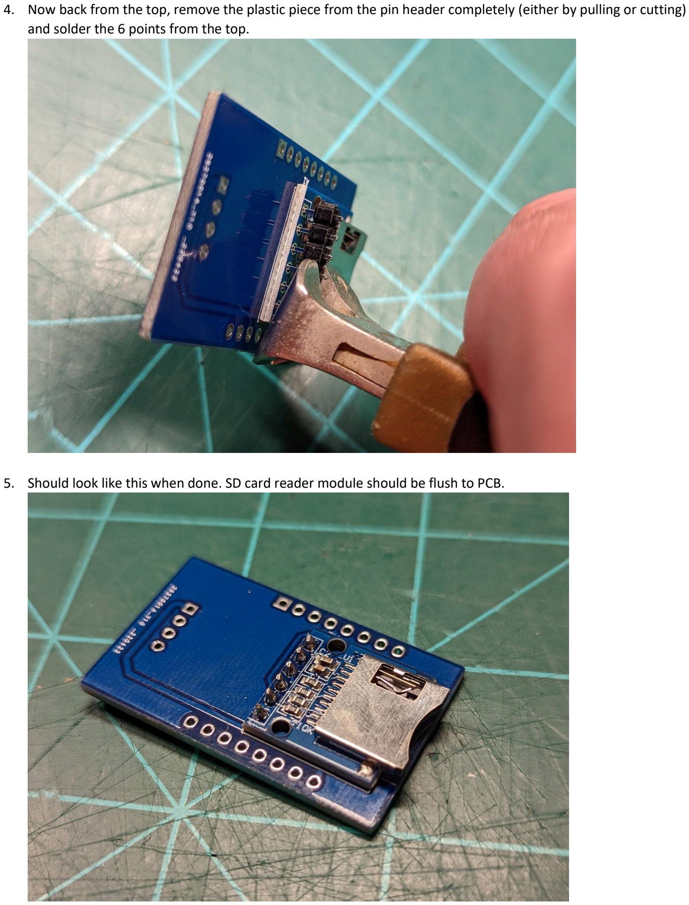
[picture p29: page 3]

4. Now back from the top, remove the plastic piece from the pin header completely (either by pulling or cutting) and solder the 6 points from the top.
5. Should look like this when done. SD card reader module should be flush to PCB.

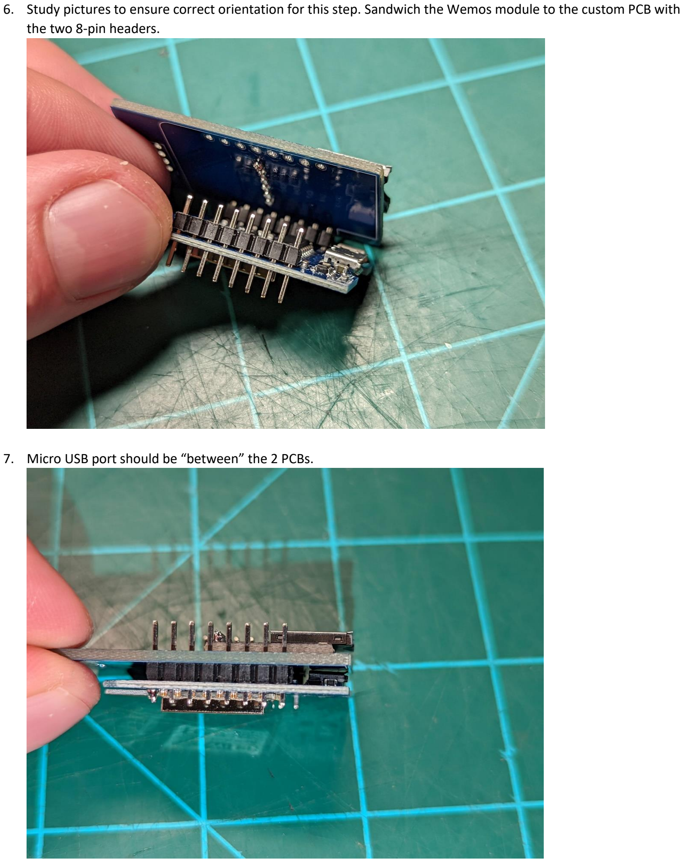
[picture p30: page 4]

6. Study pictures to ensure correct orientation for this step. Sandwich the Wemos module to the custom PCB with the two 8-pin headers.
7. Micro USB port should be “between” the 2 PCBs.

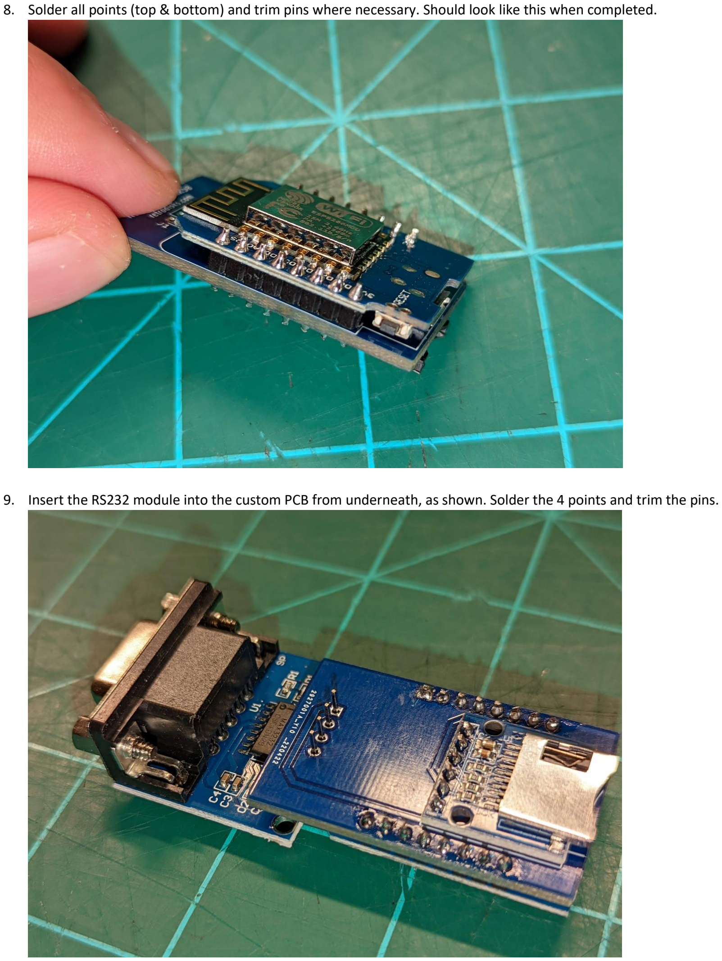
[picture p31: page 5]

8. Solder all points (top & bottom) and trim pins where necessary. Should look like this when completed.
9. Insert the RS232 module into the custom PCB from underneath, as shown. Solder the 4 points and trim the pins.

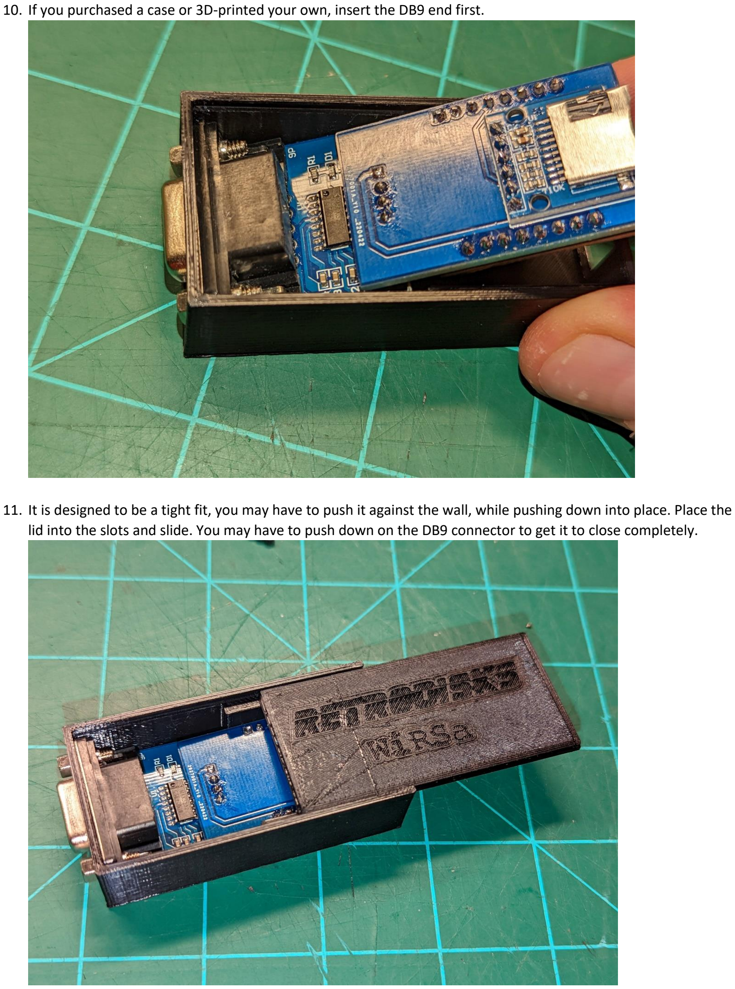
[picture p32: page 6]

10. If you purchased a case or 3D-printed your own, insert the DB9 end first.
11. It is designed to be a tight fit, you may have to push it against the wall, while pushing down into place. Place the lid into the slots and slide. You may have to push down on the DB9 connector to get it to close completely.

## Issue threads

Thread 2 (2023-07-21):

Issue downloading enclosure STL

josederas, 2023-07-21:

Closed 2023-07-22.

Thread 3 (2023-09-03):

can't do incoming connections, wifi drops

tynbendad, 2023-09-03:
from wirsa.ino (line 1025 currently):
>void readBackSwitch()
>{ //not sure why but when in a call, SW1 analog read hangs the connection
>  //only concerned about 'back' button push anyways, hence this function

this issue looks like it explains the reason why and a workaround (the wifi module also uses part of the analog to digital converter): https://github.com/esp8266/Arduino/issues/1634

your current workaround to avoid the analogRead when not in command mode, works for outgoing usage, but is insufficient for incoming connections since the wifi drops while waiting for a connection in command mode.

tynbendad, 2023-09-03:
i've tested adding a "delay(3);" after both analogRead() calls (both around current lines 1015-1018) and it no longer disconnects wifi.
(also needed to change waitKey() to be declared as void since latest IDE complained about no return statement.)

tynbendad, 2023-09-04:
also, with the latest arduino IDE (2.2.1) and libraries, this other workaround from Alwyz's original code fails (incoming connections close immediately), and is no longer needed (from around line 1094 in current .ino):
>    WiFiClient tempClient = tcpServer.available(); // this is the key to keeping the connection open
>    tcpClient = tempClient; // hand over the new connection to the global client
>    tempClient.stop();   // stop the temporary one

replacing with this lets incoming connections persist:
>    WiFiClient tcpClient = tcpServer.available();

nullvalue0, 2023-09-04:
This is awesome, thanks for the help on all this. Need to update my IDE.  If you don't mind doing a pull request, I'll merge in your modifications.

tynbendad, 2023-09-04:
Sure thing. I'm going to add the speed dial to atdt command and another change to help me debug connecting my retro systems together, then I'll put it all in a pull request.

tynbendad, 2023-09-04:
unrelated to the issue topic but fwiw, i also have a problem with the "ch340" driver on windows, the latest one that windows keeps automatically installing doesn't work with the firmware updater... i had to install one i got from sparkfun's website and then every day i've had to uninstall the new one (which puts the old one back).

tynbendad, 2023-09-05:
incoming request issue is closed with https://github.com/nullvalue0/WiRSa/pull/4 - thanks

Closed 2023-09-05.

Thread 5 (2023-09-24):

Use the microUSB port as a USB serial port (Communications Device Class).

mkatzNU, 2023-09-24:
Implement a CDC USB device on the micro USB side.

This will allow the WiRSa to be in between the two devices.

You now have the following options:
1. micro USB to DB-9 connection
2. micro USB to WiFi connection
3. DB-9 to WiFi connection.

I can place the WiRSa in between my tera term session (via the micro USB port) and my target computer connected to the DB-9.  I can then switch to local mode and have the WiRSa transmit files on the SD card to the DB-9 m(see my next suggestion).

This would allow the WiRSa to function as a very powerful USB to Serial Adapter.

mkatzNU, 2023-09-25:
CDC stands for Communications Device Class.  That is what the USB spec calls a virtual uart.

The programming of the ESP is done via a virtual comm port when the cpu is in boot mode so I know it can support it.  That is how NodeMCU-PyFlasher.exe programs the ESP flash.  If the bootloader can do it, the CPU can do it when not in bootloader mode.

mkatzNU, 2023-09-25:
I don't think this idea will work without additional hardware.  It looks like the second UART is output only because it shares a pin with the flash chip interface.

It might be worth if for some additional expense to use some kind of I2C to use Serial chip (I think FTDI makes one) to implement this.

nullvalue0, 2023-09-25:
Ok thanks for digging in. I'll close this issue for now but will keep it in mind for a future hardware revision.

Closed 2023-09-25.

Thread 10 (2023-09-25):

Add the ability to turn off the display for power savings

mkatzNU, 2023-09-25:
If the display is not being used it would be nice to turn off the display or at least the backlight in the interest of power savings.  Especially if the unit is mounted in a way where the display cannot be seen or will not be used.

nullvalue0, 2023-09-25:
I didn't even know if this would be possible so I did a little experimenting.. And there is a way to put the screen to sleep and turn it off.. However, due to ... reasons ... the command to turn the screen back on doesn't work on it's own (it requires a controller chip reset). But resetting the Wemos and/or a soft reboot does bring the screen back on. So, as long as you were ok with these limitations I could add it as a feature.

mkatzNU, 2023-09-25:
As an option I don't see why we don't add it.

If the display is off, changing the ATDISP=ON could also force a prompted reset as could pushing the home button while the display is off.

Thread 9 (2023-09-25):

allow for connecting two WiRSa modules together wirelessly

mkatzpdp, 2023-09-25:
Allow for connected a dumb device to the WiRSa at each end (via the DB-9) port.

This allows for a terminal to be connected to a non-network serial port on a computer wirelessly.

Terminal <-> WiRSa <-> WiRSa <-> Computer

john-clark, 2023-09-25:
Why not just?

Terminal <-> WiRSa <-> AP <-> WiRSa <-> Computer

Seems like better solution than adding more software to the device.

nullvalue0, 2023-09-25:
I think I see what you're trying to do, this is an interesting idea. And in both cases I think there's some screen options I'd want to add to simplify making this type of connection...

Actually I wonder if it would be possible now.. On WiRSa #1, add a speed dial entry for WiRSa #2's telnet address/port. Then you should be able to initiate the connection from WiRSa #1 using the screen. Haven't tried this but should be possible in theory. Let me know if that works.

mkatzNU, 2023-09-25:
I need to build the other kit.

It would be nice if they could connect without operator intervention.  Power them up and due to settings in NVRAM have them automatically connect.

mkatzNU, 2023-09-25:
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

That is exactly what I meant.  Point to point would be nice but only if there was no router near by or greater security than offered by standard WiFi encryption.

The main goal is for it to be hands free once setup.

starfishetl, 2023-09-25:
> It would be nice if they could connect without operator intervention. Power them up and due to settings in NVRAM have them automatically connect.

There is a setting to change the default mode to MODEM mode. This gets us halfway there. Would need to add an option to auto-dial out to a speed dial # when MODEM mode is entered. This wouldn't be hard to add.

mkatzNU, 2023-09-25:
Thank you for listening to my endless ideas.

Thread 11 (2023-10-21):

Add some margin to the 3D Printed Case

dvincent747, 2023-10-21:
When assembling a WiRSa, there's almost no margin of tolerance for the height between the sandwiched WiRSa and the 3D printed case. The piece of foam tape for the display spacing in my particular parts kit was a little thick, and I didn't squish it down when soldering the display to the board. I only pressed it so it would adhere and then laid it down to solder. The assembled device wound up about a millimeter and change too tall and sliding the top cover in was really tight for my liking.

It might make sense to adjust the top lid to add some margin and/or include a recess in the bottom to give the Weimos module a place to go so it's not pressed against the bottom of the case. Or make the case a little taller and use foam tape as spacers and a way to keep the case tight.

I'm not a case or 3D designer, so I can't contribute a fix, but hopefully this feedback can help for future builders.

nullvalue0, 2023-11-11:
You're right, this has been an issue. I've been using a piece of paper or pencil eraser to gently push the screen down as I push the cover of the top - but I've now corrected the issue by making the enclosure slightly taller. If you'd like a replacement, let me know and I can send you one for cost of shipping.

Closed 2023-11-11.

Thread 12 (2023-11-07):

IP information keeps getting lost

johngalt01, 2023-11-07:
I keep having to power cycle the modem because the IP information will suddenly become not set.

i started using the modem last night under 2.11.

while trying to dialing telnet bbs i would start seeing no carrier messages. when i checked ATI it would show
the IP information was blank and i would have to power cycle the modem so it would reconnect to my wifi network and propagate all
the IP information again.
then if i disconnected the IP information would be blanked again or if i tried to HTTP into the modem it would again lose the IP configuration again.
became quite annoying to constantly power cycle.

also connecting to the modem over HTTP only seemed to work for a few seconds on power cycle then the IP information would be lost again.

i have theoldnet wifi modem and it has a bunch of issues as well but it does not constantly lose the IP setting information.

nullvalue0, 2023-11-11:
When the modem loses the IP information under the ATI command, is it also losing all wifi connectivity? I'm curious if you try an ATC0 (disconnect wifi) and ATC1 command (connect wifi) if this re-establishes the connection? Not trying to propose this as a solution, just trying to gather some more information. Does anything appear over the serial port when the disconnect occurs, or does the wifi logo disappear on the oled display? I may have to add some additional logging to determine what's causing it.

johngalt01, 2023-11-23:
sorry i forgot i posted. the next time i have the modem setup i will try ATC0 and ATC1.

i have been down a rabbit hole for a few weeks with vintage computer issues i'm starting to get things sorted again.
will report back.

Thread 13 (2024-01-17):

Is it possible to use the Wirsa V2 via SLIP?

keenerb, 2024-01-17:
Not an issue of course, but I don't see any mention in the documentation.  Many of the ESP8266 devices can be used that way, it seems, but I'm not familiar enough with how these things work to know if that applies to your device as well.

nullvalue0, 2024-01-17:
No unfortunately it is not possible with the V2 due to the CTS/RTS pins not being connected. I have however recently started work on a new version which should support it. I will leave this open as an enhancement request, and will update here if/when I get it working. :)

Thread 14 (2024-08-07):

Automate connecting to wifi and to server using file in micro sd

kepak1, 2024-08-07:
I got an idea, it would be super to get.

If the device find file on microSD card during boot, it would be automatically(or after pressing any button) done everything from this file. For example i got dumb terminal and I connect WiRSa to this device. After powering on (and receive enter from terminal) the device would automatically connect to wifi, and then connect to one specific telnet server.

It wold be useful to make some interesting prompts during retro convents etc.
My first idea (but Im almost sure that I won't implement it, just selling to the others) is retro themed restaurant. There is something like minitel terminal ( modded to RS232, i choose this one because it looks relatively small on the foto) on every table. You can look on the menu, order dish, call waiter, select payment method etc.

In the matter of fact i saw something like this on Chill's  when I was in the US, and thats a combination of this device and terminal from Fallout.

nullvalue0, 2024-09-25:
Hey just now seeing this.. I like this idea.. kind of like an autoexec file, and would just allow you to put a series of AT commands.. I'm back to focusing on a V3.. I'll aim for adding this in the next firmware release.

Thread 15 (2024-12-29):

V3 enclosure scad/stls are for V2 despite the name

thisspaceleftblank, 2024-12-29:
As the title says...

nullvalue0, 2024-12-29:
Ah, thanks for bringing that to my attention - I just updated the files. I'm still making some very minor adjustments to the dimensions and actually currently have a print going - fingers crossed. Let me know how yours turns out!

thisspaceleftblank, 2025-01-22:
Is there a module or library you are using with scad to get the symbols on the cover? My render shows 7, 5, = and 8 instead.

nullvalue0, 2025-01-22:
Ah those symbols are being loaded from the "Webdings" font... it's not included in the base fonts though for OpenSCAD by defaults, so you have to add it - however i'm not finding the instructions i used atm.. i'll keep looking..  Also, FYI i just updated the enclosure files with a couple small adjustments I've made recently

nullvalue0, 2025-01-22:
Ah that's what it is, in Windows it needs to be a font that has been installed for all users.. see: https://www.reddit.com/r/3Dprinting/comments/ee8011/anyone_know_how_to_add_a_font_to_openscad/

thisspaceleftblank, 2025-01-22:
Linux. Just gonna use ascii chars.  Thanks.

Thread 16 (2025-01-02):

Reboot through Serial or through the onboard controls freezes

Nephrite-FM, 2025-01-02:
on a new WiRSa v3 board, loaded with WiRSa Build 3.01, the device crashes and hangs whenever you choose the options 'Reboot' or 'Factory Reset'.

Is 3.01 an official release for the new devices you are selling? Currently your GIT release version is at 2.11.

What changed going from 2.11 to 3.01, other than the rebooting apparently breaking?

Nephrite-FM, 2025-01-02:
So I see here, 3.01 has:

void(* resetFunc) (void) = 0; //declare reset function @ address 0

It matches the old version.

Perhaps the new ESP32 Arduino board no longer responds to this...

nullvalue0, 2025-01-02:
You're definitely right about this, ESP32 must do this differently - I'll see what I can find

nullvalue0, 2025-01-02:
Ok I've pushed an update for 3.02.. You can download the .bin in the Firmware folder and [flash it using ESP32FlashTool](https://github.com/nullvalue0/WiRSa/tree/main?tab=readme-ov-file#flashing-the-firmware). I still need to get OTA updates working again.

Nephrite-FM, 2025-01-03:
ESP.restart(); fixed the rebooting!  Thanks.

Nephrite-FM, 2025-01-03:
ESP.restart(); fixed the rebooting! Thanks.

Closed 2025-01-03.

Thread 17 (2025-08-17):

v3 latest firmware

theshinyknight, 2025-08-17:
There seems to be only a version for V2 Wirsa; while the V3 firmware is not available. Will the V3 firmware get released here too? Also what is the size of the JST used for the battery connector on the small board? It is not a standard 2 pin JST right? Thanks

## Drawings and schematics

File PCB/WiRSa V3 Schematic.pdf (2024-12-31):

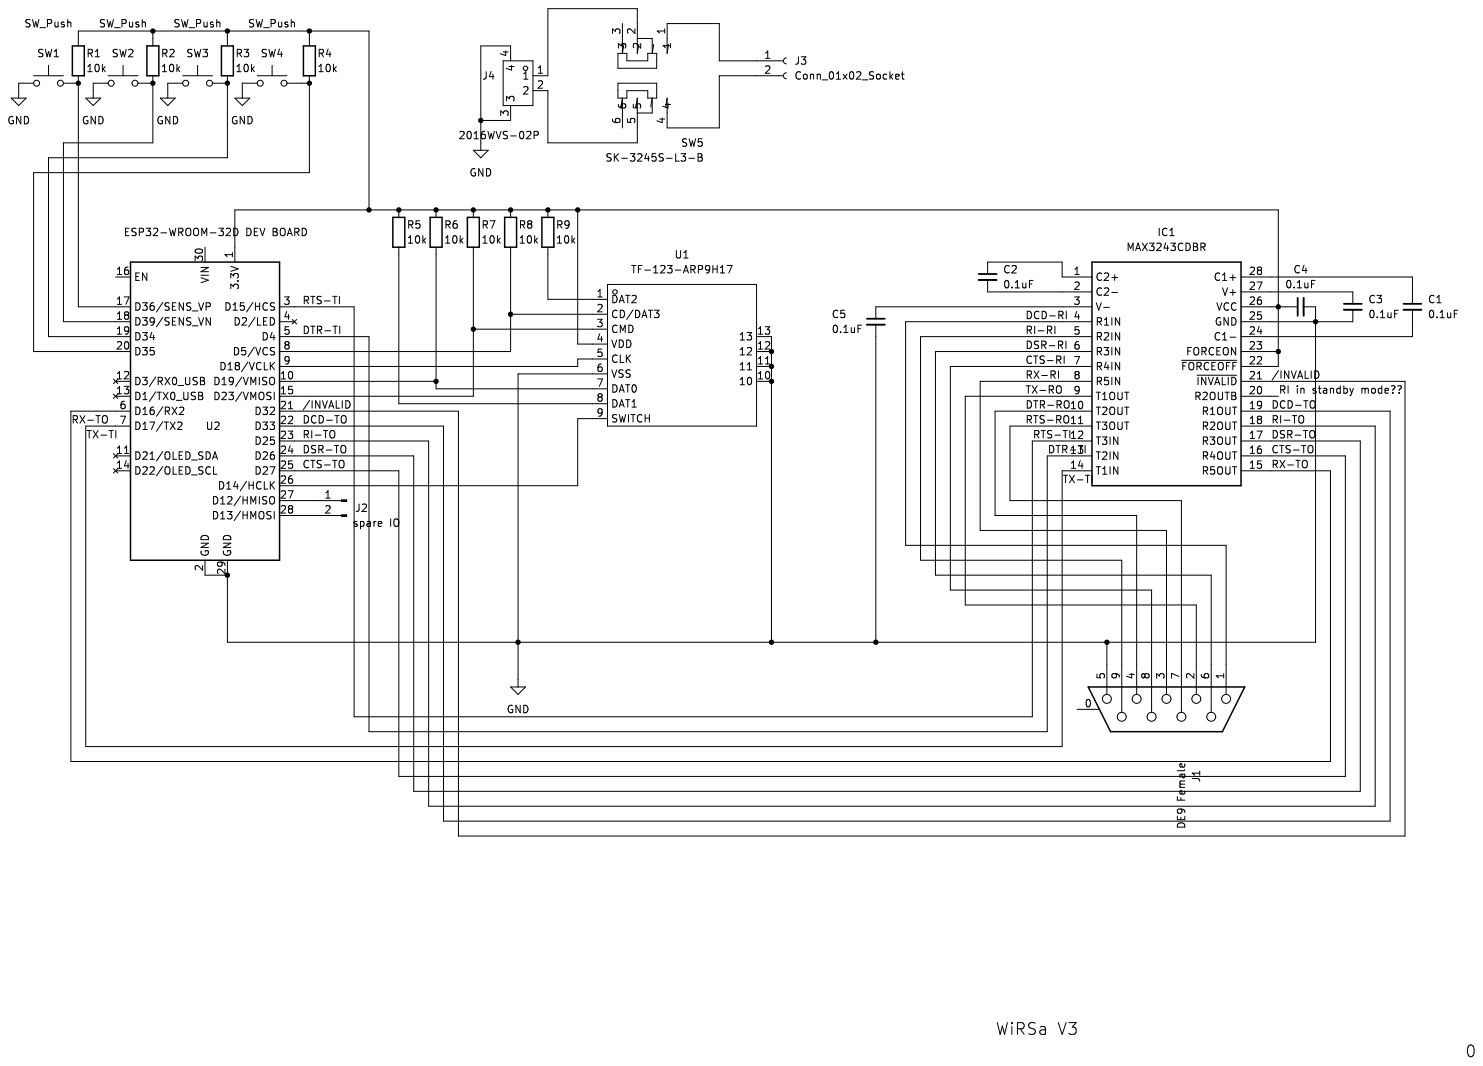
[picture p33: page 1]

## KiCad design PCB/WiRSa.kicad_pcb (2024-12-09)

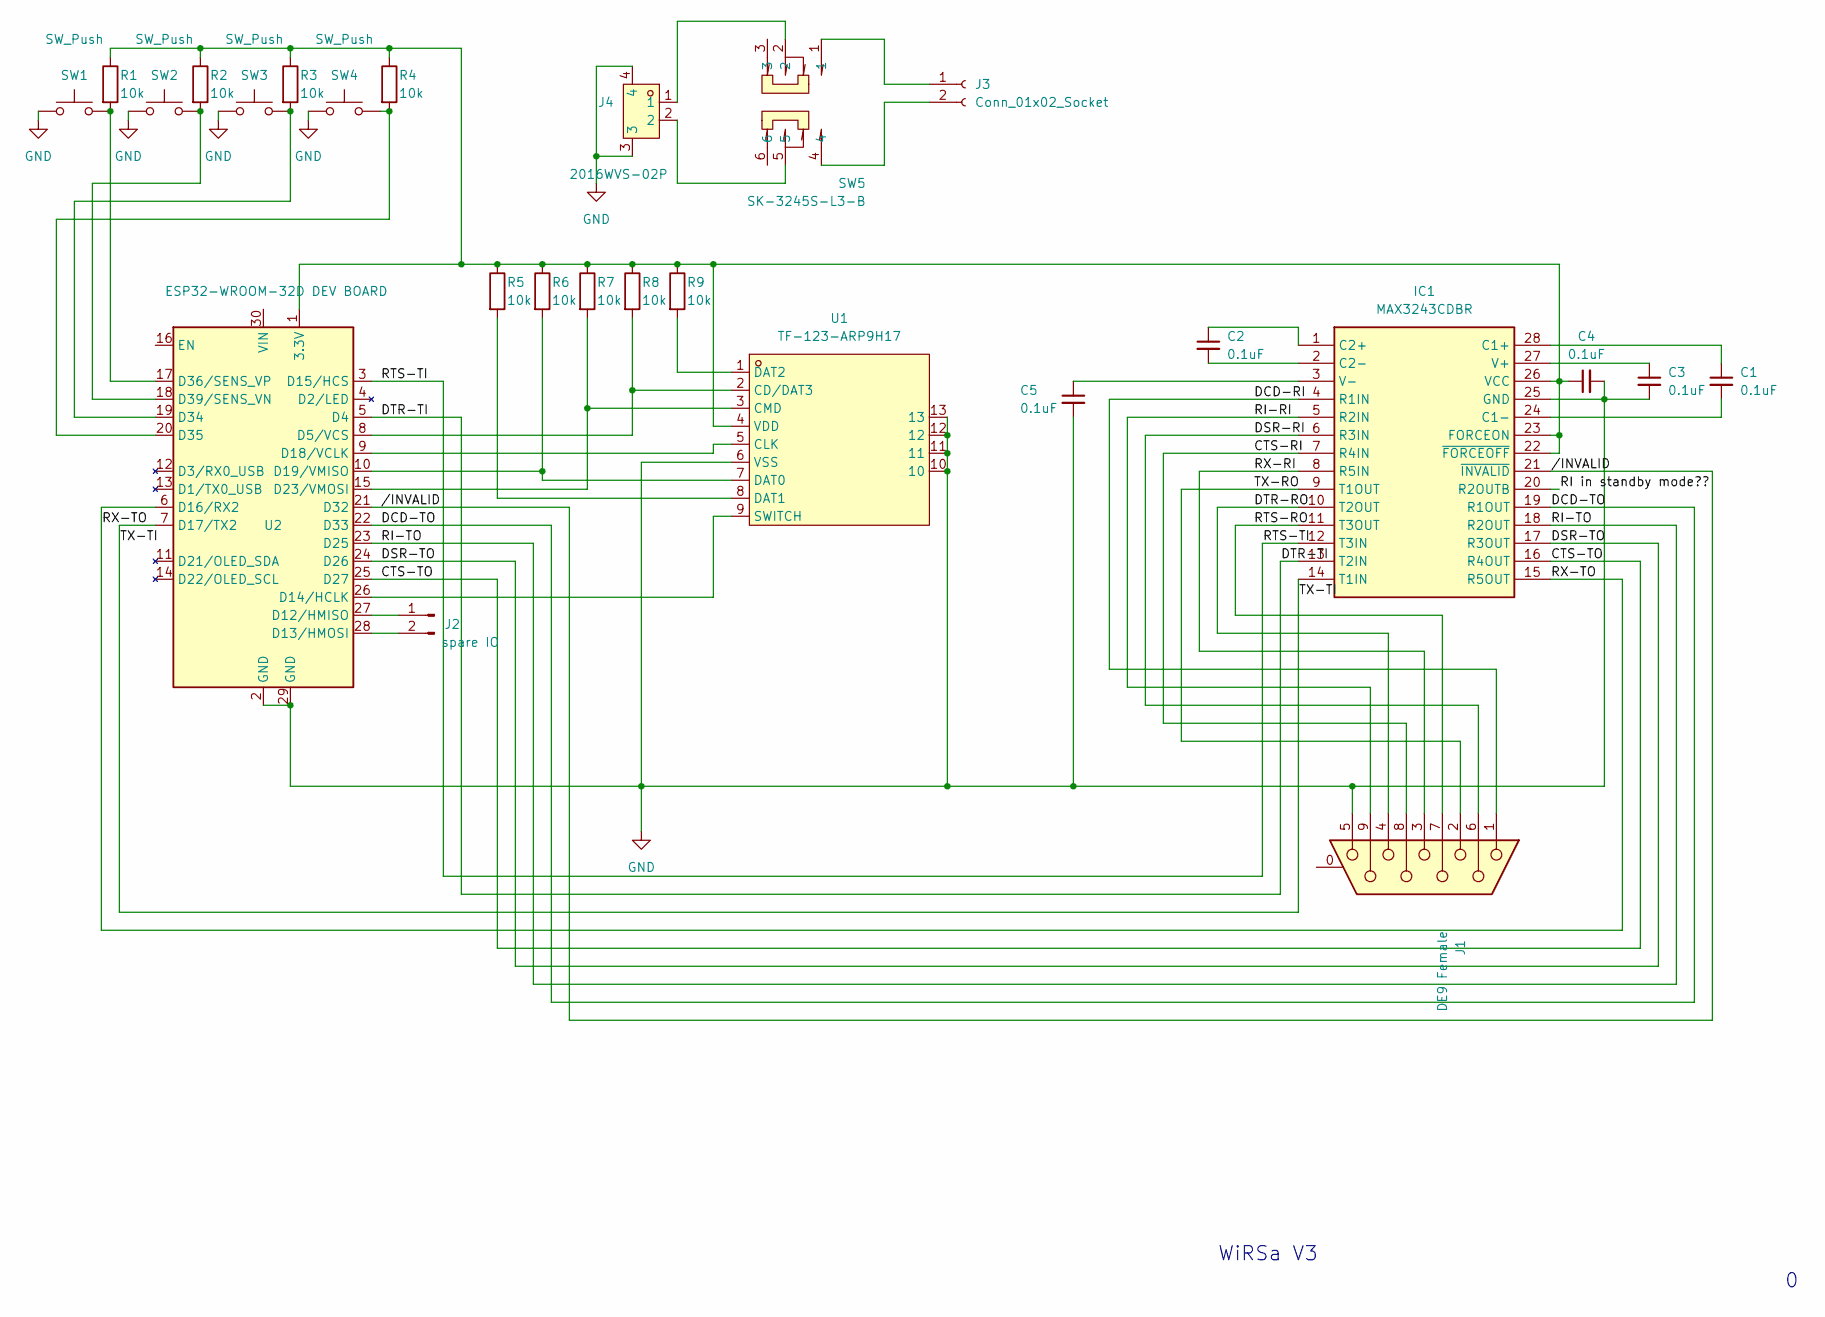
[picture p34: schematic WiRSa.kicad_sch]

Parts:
C1, C2, C3, C4, C5: 0.1uF; C_0603_1608Metric; LCSC C14663
IC1: MAX3243CDBR; SSOP-28_L10.2-W5.3-P0.65-LS7.8-BL; LCSC Part C414614
J1: DE9 Female; DSUB-9_Female_Horizontal_P2.77x2.84mm_EdgePinOffset4.94mm_H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
J2: spare IO; PinHeader_1x02_P2.54mm_Vertical
J3: Conn_01x02_Socket; PinHeader_1x02_P2.54mm_Vertical
J4: 2016WVS-02P; CONN-SMD_P2.00_X2016WVS-02-9TSW; LCSC Part C5448068
R1, R2, R3, R4, R5, R6, R7, R8, R9: 10k; R_0603_1608Metric; LCSC C25804
SW1, SW2, SW3, SW4: SW_Push; SW_Tactile_SPST_Angled_PTS645Vx58-2LFS
SW5: SK-3245S-L3-B; SW-SMD_SK-3245S-L3-B; LCSC Part C405954
U1: TF-123-ARP9H17; TF-SMD_TF-123-ARP9H15; LCSC Part C2982548
U2: ESP32-WROOM-32D DEV BOARD; ESP32-C3-DevKitC-02

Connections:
/CTS-RI: IC1.7 (R4IN), J1.8
/CTS-TO: IC1.16 (R4OUT), U2.25 (D27)
/DCD-RI: IC1.4 (R1IN), J1.1
/DCD-TO: IC1.19 (R1OUT), U2.22 (D33)
/DSR-RI: IC1.6 (R3IN), J1.6
/DSR-TO: IC1.17 (R3OUT), U2.24 (D26)
/DTR-RO: IC1.10 (T2OUT), J1.4
/DTR-TI: IC1.13 (T2IN), U2.5 (D4)
/RI in standby mode??: IC1.20 (R2OUTB)
/RI-RI: IC1.5 (R2IN), J1.9
/RI-TO: IC1.18 (R2OUT), U2.23 (D25)
/RTS-RO: IC1.11 (T3OUT), J1.7
/RTS-TI: IC1.12 (T3IN), U2.3 (D15/HCS)
/RX-RI: IC1.8 (R5IN), J1.3
/RX-TO: IC1.15 (R5OUT), U2.6 (D16/RX2)
/TX-RO: IC1.9 (T1OUT), J1.2
/TX-TI: IC1.14 (T1IN), U2.7 (D17/TX2)
//INVALID: IC1.21 (~INVALID), U2.21 (D32)
GND: C3.2, C4.2, C5.2, IC1.25 (GND), J1.5, J4.3, J4.4, SW1.1, SW2.1, SW3.1, SW4.1, U1.6 (VSS), U1.10, U1.11, U1.12, U1.13, U2.2 (GND), U2.29 (GND)
unnamed: C1.1, IC1.28 (C1+)
unnamed: C1.2, IC1.24 (C1-)
unnamed: C2.1, IC1.1 (C2+)
unnamed: C2.2, IC1.2 (C2-)
unnamed: C4.1, IC1.22 (~FORCEOFF), IC1.23 (FORCEON), IC1.26 (VCC), R1.1, R2.1, R3.1, R4.1, R5.1, R6.1, R7.1, R8.1, R9.1, U1.4 (VDD), U2.1 (3.3V)
unnamed: C3.1, IC1.27 (V+)
unnamed: C5.1, IC1.3 (V-)
unnamed: J2.1, U2.27 (D12/HMISO)
unnamed: J2.2, U2.28 (D13/HMOSI)
unnamed: J3.1, SW5.1
unnamed: J3.2, SW5.4
unnamed: J4.1, SW5.2
unnamed: J4.2, SW5.5
unnamed: R8.2, U1.2 (CD/DAT3), U2.8 (D5/VCS)
unnamed: U1.5 (CLK), U2.9 (D18/VCLK)
unnamed: R7.2, U1.3 (CMD), U2.15 (D23/VMOSI)
unnamed: R6.2, U1.7 (DAT0), U2.10 (D19/VMISO)
unnamed: R5.2, U1.8 (DAT1)
unnamed: R9.2, U1.1 (DAT2)
unnamed: U1.9 (SWITCH), U2.26 (D14/HCLK)
unnamed: R3.2, SW3.2, U2.19 (D34)
unnamed: R4.2, SW4.2, U2.20 (D35)
unnamed: R1.2, SW1.2, U2.17 (D36/SENS_VP)
unnamed: R2.2, SW2.2, U2.18 (D39/SENS_VN)

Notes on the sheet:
WiRSa V3

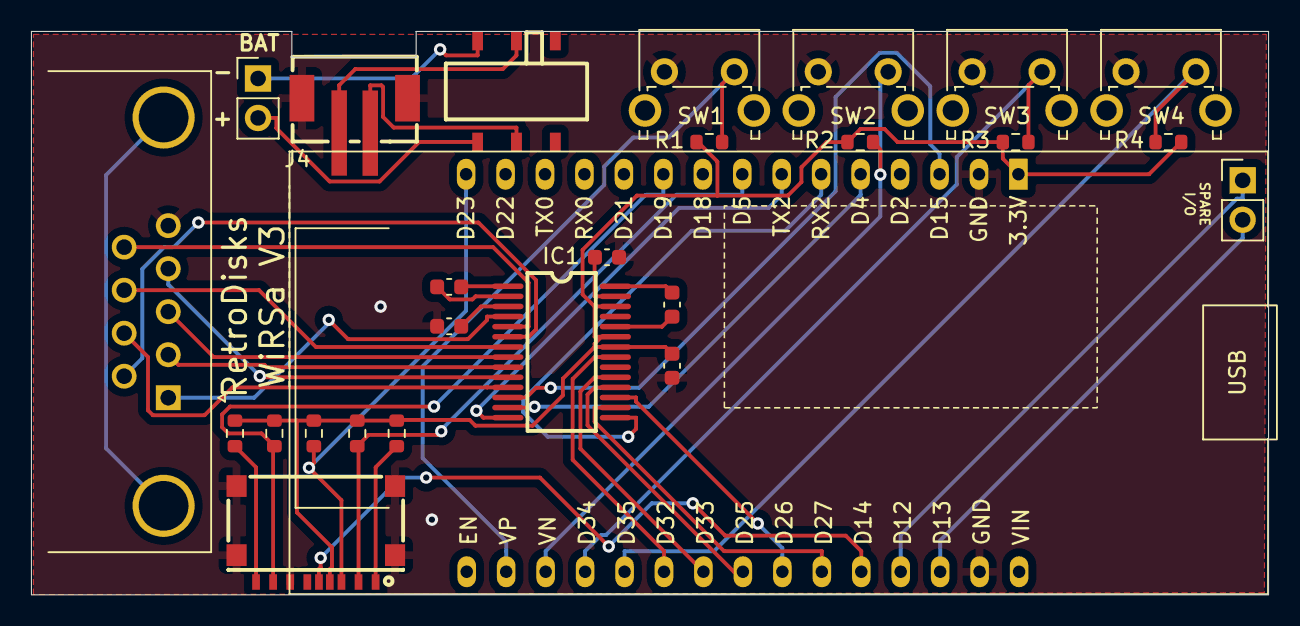
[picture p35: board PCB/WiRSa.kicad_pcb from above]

Board: 2 copper layers, 79.6 x 36.3 mm, 26 parts (0 on the bottom side), 42 nets.

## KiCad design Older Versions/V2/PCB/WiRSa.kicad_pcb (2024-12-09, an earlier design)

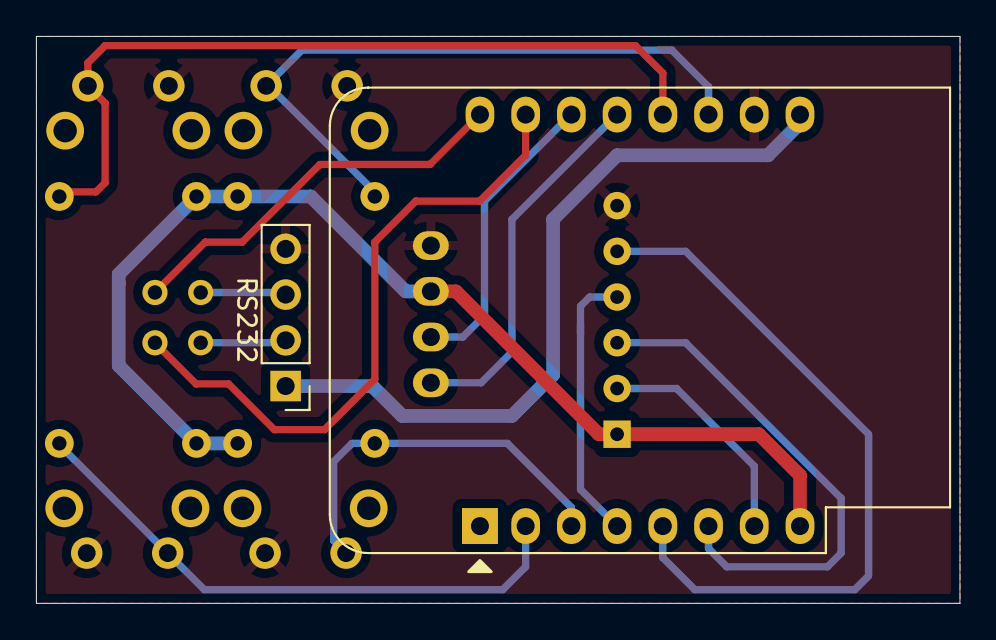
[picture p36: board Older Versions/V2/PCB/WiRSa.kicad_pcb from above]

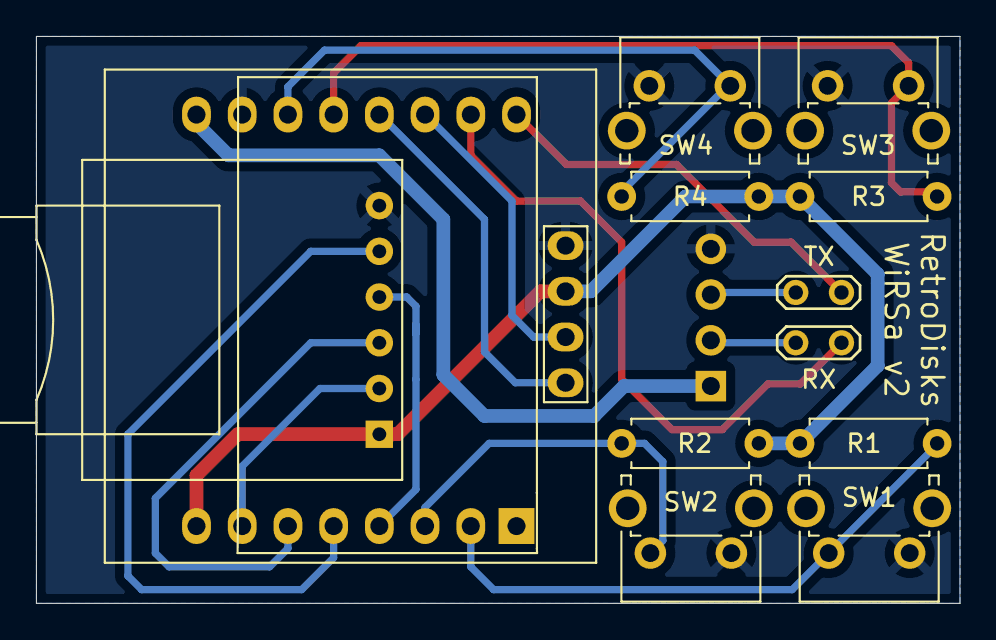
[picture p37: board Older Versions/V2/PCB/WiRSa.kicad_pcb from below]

Board: 2 copper layers, 51.3 x 31.5 mm, 14 parts (12 on the bottom side), 17 nets.

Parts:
A1: SD_Card_Module
Brd1: SSD1306; 128x64OLED
R1, R2, R3, R4: 10k; R_Axial_DIN0207_L6.3mm_D2.5mm_P7.62mm_Horizontal
RS232: RS232_TTL_Adapter; PinHeader_1x04_P2.54mm_Vertical
RX: RX; TestPoint_2Pads_Pitch2.54mm_Drill0.8mm
SW1, SW2, SW3, SW4: SW_Push; SW_Tactile_SPST_Angled_PTS645Vx58-2LFS
TX: TX; TestPoint_2Pads_Pitch2.54mm_Drill0.8mm
U1: WeMos_D1_mini; WEMOS_D1_mini_light

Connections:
GND: A1.6 (GND), Brd1.1 (GND), RS232.4 (GND), SW1.1, SW2.1, SW3.1, SW4.1, U1.10 (GND)
unnamed: A1.1 (3V3), Brd1.2 (VCC), R1.1, R2.1, R3.1, R4.1, U1.8 (3V3)
unnamed: A1.2 (CS), U1.7 (CS/D8)
unnamed: A1.3 (MOSI), U1.6 (MOSI/D7)
unnamed: A1.4 (CLK), U1.4 (SCK/D5)
unnamed: A1.5 (MISO), U1.5 (MISO/D6)
unnamed: Brd1.3 (SCL), U1.14 (SCL/D1)
unnamed: Brd1.4 (SDA), U1.13 (SDA/D2)
unnamed: RS232.1 (VCC), U1.9 (5V)
unnamed: RS232.2 (RXD), RX.1 (A)
unnamed: RS232.3 (TXD), TX.1 (A)
unnamed: RX.2 (B), U1.15 (RX)
unnamed: TX.2 (B), U1.16 (TX)
unnamed: R1.2, SW1.2, U1.2 (A0)
unnamed: R2.2, SW2.2, U1.3 (D0)
unnamed: R3.2, SW3.2, U1.12 (D3)
unnamed: R4.2, SW4.2, U1.11 (D4)

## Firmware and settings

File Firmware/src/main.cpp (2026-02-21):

/**************************************************************************
   RetroDisks WiRSa v3 - Wi-Fi RS232 Serial Modem Adapter with File Transfer features
   Copyright (C) 2024 Aron Hoekstra <nullvalue@gmail.com>

   based on:
     Virtual modem for ESP8266
     https://github.com/jsalin/esp8266_modem
     Copyright (C) 2015 Jussi Salin <salinjus@gmail.com>
   
   and the improvements added by:
     WiFi SIXFOUR - A virtual WiFi modem based on the ESP 8266 chipset by Alwyz
     https://1200baud.wordpress.com/2017/03/04/build-your-own-9600-baud-c64-wifi-modem-for-20/
   
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
  THE SOFTWARE IS PROVIDED "AS IS", WITHOUT WARRANTY OF ANY KIND, EXPRESS OR
  IMPLIED, INCLUDING BUT NOT LIMITED TO THE WARRANTIES OF MERCHANTABILITY,
  FITNESS FOR A PARTICULAR PURPOSE AND NONINFRINGEMENT. IN NO EVENT SHALL THE
  AUTHORS OR COPYRIGHT HOLDERS BE LIABLE FOR ANY CLAIM, DAMAGES OR OTHER
  LIABILITY, WHETHER IN AN ACTION OF CONTRACT, TORT OR OTHERWISE, ARISING FROM,
  OUT OF OR IN CONNECTION WITH THE SOFTWARE OR THE USE OR OTHER DEALINGS IN THE
  SOFTWARE.
 **************************************************************************
 This software uses libraries published by Adafruit for LCD screen control
 Adafruit_SSD1306 & Adafruit_GFX.
 **************************************************************************
 This software uses the LinkedList library by Ivan Seidel
 http://github.com/ivanseidel/LinkedList
 **************************************************************************
 This software uses the arduino-timer libary by
 https://github.com/contrem/arduino-timer
 **************************************************************************/

 /*
 changes 3.10
 - modified signal monitor to show on screen while in modem mode
 - fixed telnet call mode to assert DCD
 - fixed some pin polarity issues

 changes 3.09
 - when S0=1 (auto-answer), telnet goes to RING/CONNECT/DCD
 - added ATQ0/ATQ1 and ATS2=N commands

 changes 3.08
 - fixed wifi password entry via screen/buttons
 - implemented AT&D0-3 (DTR control)
 - DSR and RI pins now driven as outputs per RS-232 standard
 
 changes 3.07
 - SLIP/PPP modes bug fixes for linux compatibility (slattach, pppd)

 changes 3.06
 - added port forwarding to SLIP/PPP modes
 
 changes 3.05
 - added SLIP mode/feature
 - added greatly improved web config

 changes 3.04
 - added PPP mode/feature
 - added USB Debug output option

 changes 3.03
 - refactored code, using platform.io now instead of Arduino IDE
 - fixed SD card r/w
 - fixed IP display (ATI etc)
 - added ZModem support
 - fix OTA update
 */

#include <Arduino.h>
#include <WiFi.h>
#include <HTTPClient.h>
#include <HTTPUpdate.h>
#include <WiFiClient.h>
#include <WebServer.h>
#include <EEPROM.h>
#include <ESPmDNS.h>
#include <LinkedList.h>
//#include <SPI.h>
#include <Wire.h>
#include <Adafruit_GFX.h>
#include <Adafruit_SSD1306.h>
#include "SD.h"
//#include "FS.h"
#include "CRC16.h"
#include "CRC.h"
#include "arduino-timer.h"
#include <HardwareSerial.h>

// Project modules
#include "globals.h"  // ZModem constants and structures
#include "serial_io.h"
#include "settings.h"
#include "network.h"
#include "display_menu.h"
#include "firmware.h"
#include "playback.h"
#include "file_transfer.h"
#include "modem.h"
#include "slip_mode.h"     // SLIP gateway mode
#include "ppp_mode.h"      // PPP gateway mode
#include "wifi_setup.h"    // WiFi setup wizard
#include "diagnostics.h"   // Diagnostic tools

#define VERSIONA 0
#define VERSIONB 1
#define VERSION_ADDRESS 0    // EEPROM address
#define VERSION_LEN     2    // Length in bytes
#define SSID_ADDRESS    2
#define SSID_LEN        32
#define PASS_ADDRESS    34
#define PASS_LEN        63
#define IP_TYPE_ADDRESS 97   // for future use
#define STATIC_IP_ADDRESS 98 // length 4, for future use
#define STATIC_GW       102  // length 4, for future use
#define STATIC_DNS      106  // length 4, for future use
#define STATIC_MASK     110  // length 4, for future use
#define BAUD_ADDRESS    111
#define ECHO_ADDRESS    112
#define SERVER_PORT_ADDRESS 113 // 2 bytes
#define AUTO_ANSWER_ADDRESS 115 // 1 byte
#define TELNET_ADDRESS  116     // 1 byte
#define VERBOSE_ADDRESS 117
#define PET_TRANSLATE_ADDRESS 118
#define FLOW_CONTROL_ADDRESS 119
#define PIN_POLARITY_ADDRESS 120
#define DIAL0_ADDRESS   200
#define DIAL1_ADDRESS   250
#define DIAL2_ADDRESS   300
#define DIAL3_ADDRESS   350
#define DIAL4_ADDRESS   400
#define DIAL5_ADDRESS   450
#define DIAL6_ADDRESS   500
#define DIAL7_ADDRESS   550
#define DIAL8_ADDRESS   600
#define DIAL9_ADDRESS   650
#define BUSY_MSG_ADDRESS 700
#define BUSY_MSG_LEN    80
#define ORIENTATION_ADDRESS 780
#define DEFAULTMODE_ADDRESS 790
#define SERIALCONFIG_ADDRESS 791
// LAST_ADDRESS is now defined in globals.h (880 for SLIP config)

#define SWITCH_PIN 0       // GPIO0 (programmind mode pin)
#define LED_PIN 2          //LED_BUILTIN          // Status LED

#define DCD_PIN 33         // DCD Carrier Status
#define RTS_PIN 15         // RTS Request to Send, connect to host's CTS pin
#define CTS_PIN 27         // CTS Clear to Send, connect to host's RTS pin

#define DTR_PIN 4          // DTR Data Terminal Ready
#define DSR_PIN 26         // DSR Data Set Ready
#define RI_PIN  25         // RI Ring Indicator

#define SW1_PIN 36         //DOWN
#define SW2_PIN 39         //BACK
#define SW3_PIN 34         //ENTER
#define SW4_PIN 35         //UP

#define MODE_MAIN 0
#define MODE_MODEM 1
#define MODE_FILE 2
#define MODE_PLAYBACK 3
#define MODE_SETTINGS 4
#define MODE_SETBAUD 5
#define MODE_LISTFILE 6
#define MODE_ORIENTATION 7
#define MODE_DEFAULTMODE 8
#define MODE_PROTOCOL 9
#define MODE_SERIALCONFIG 10

#define MENU_BOTH 0 //show menu on both serial port & display using first letter as selector
#define MENU_NUM  1 //show menu on both serial port & display but serial uses a numeric selector - has a limit of 10 items because the input currently returns after 1 character entry
#define MENU_DISP 2 //show menu on display only

#define XFER_SEND 0
#define XFER_RECV 1

#define SCREEN_WIDTH 128 // OLED display width, in pixels
#define SCREEN_HEIGHT 64 // OLED display height, in pixels
#define OLED_RESET     -1 // Reset pin # (or -1 if sharing Arduino reset pin)
#define SCREEN_ADDRESS 0x3C ///< See datasheet for Address;
Adafruit_SSD1306 display(SCREEN_WIDTH, SCREEN_HEIGHT, &Wire, OLED_RESET);

//SD Card Pins
#define SD_CS 5
#define SPI_MOSI 23 
#define SPI_MISO 19
#define SPI_SCK 18  

#define RXD2 16
#define TXD2 17

// ZMODEM constants are defined in globals.h
// ZMODEM Context - comprehensive protocol state
ZModemContext zmCtx;

uint8_t zBuf[4096];  // Increased from 2048 to 4096 to reduce CRC errors from WiFi interrupt delays

// CRC-16 CCITT table
const uint16_t crc16_ccitt_table[256] PROGMEM = {
  0x0000, 0x1021, 0x2042, 0x3063, 0x4084, 0x50a5, 0x60c6, 0x70e7,
  0x8108, 0x9129, 0xa14a, 0xb16b, 0xc18c, 0xd1ad, 0xe1ce, 0xf1ef,
  0x1231, 0x0210, 0x3273, 0x2252, 0x52b5, 0x4294, 0x72f7, 0x62d6,
  0x9339, 0x8318, 0xb37b, 0xa35a, 0xd3bd, 0xc39c, 0xf3ff, 0xe3de,
  0x2462, 0x3443, 0x0420, 0x1401, 0x64e6, 0x74c7, 0x44a4, 0x5485,
  0xa56a, 0xb54b, 0x8528, 0x9509, 0xe5ee, 0xf5cf, 0xc5ac, 0xd58d,
  0x3653, 0x2672, 0x1611, 0x0630, 0x76d7, 0x66f6, 0x5695, 0x46b4,
  0xb75b, 0xa77a, 0x9719, 0x8738, 0xf7df, 0xe7fe, 0xd79d, 0xc7bc,
  0x48c4, 0x58e5, 0x6886, 0x78a7, 0x0840, 0x1861, 0x2802, 0x3823,
  0xc9cc, 0xd9ed, 0xe98e, 0xf9af, 0x8948, 0x9969, 0xa90a, 0xb92b,
  0x5af5, 0x4ad4, 0x7ab7, 0x6a96, 0x1a71, 0x0a50, 0x3a33, 0x2a12,
  0xdbfd, 0xcbdc, 0xfbbf, 0xeb9e, 0x9b79, 0x8b58, 0xbb3b, 0xab1a,
  0x6ca6, 0x7c87, 0x4ce4, 0x5cc5, 0x2c22, 0x3c03, 0x0c60, 0x1c41,
  0xedae, 0xfd8f, 0xcdec, 0xddcd, 0xad2a, 0xbd0b, 0x8d68, 0x9d49,
  0x7e97, 0x6eb6, 0x5ed5, 0x4ef4, 0x3e13, 0x2e32, 0x1e51, 0x0e70,
  0xff9f, 0xefbe, 0xdfdd, 0xcffc, 0xbf1b, 0xaf3a, 0x9f59, 0x8f78,
  0x9188, 0x81a9, 0xb1ca, 0xa1eb, 0xd10c, 0xc12d, 0xf14e, 0xe16f,
  0x1080, 0x00a1, 0x30c2, 0x20e3, 0x5004, 0x4025, 0x7046, 0x6067,
  0x83b9, 0x9398, 0xa3fb, 0xb3da, 0xc33d, 0xd31c, 0xe37f, 0xf35e,
  0x02b1, 0x1290, 0x22f3, 0x32d2, 0x4235, 0x5214, 0x6277, 0x7256,
  0xb5ea, 0xa5cb, 0x95a8, 0x8589, 0xf56e, 0xe54f, 0xd52c, 0xc50d,
  0x34e2, 0x24c3, 0x14a0, 0x0481, 0x7466, 0x6447, 0x5424, 0x4405,
  0xa7db, 0xb7fa, 0x8799, 0x97b8, 0xe75f, 0xf77e, 0xc71d, 0xd73c,
  0x26d3, 0x36f2, 0x0691, 0x16b0, 0x6657, 0x7676, 0x4615, 0x5634,
  0xd94c, 0xc96d, 0xf90e, 0xe92f, 0x99c8, 0x89e9, 0xb98a, 0xa9ab,
  0x5844, 0x4865, 0x7806, 0x6827, 0x18c0, 0x08e1, 0x3882, 0x28a3,
  0xcb7d, 0xdb5c, 0xeb3f, 0xfb1e, 0x8bf9, 0x9bd8, 0xabbb, 0xbb9a,
  0x4a75, 0x5a54, 0x6a37, 0x7a16, 0x0af1, 0x1ad0, 0x2ab3, 0x3a92,
  0xfd2e, 0xed0f, 0xdd6c, 0xcd4d, 0xbdaa, 0xad8b, 0x9de8, 0x8dc9,
  0x7c26, 0x6c07, 0x5c64, 0x4c45, 0x3ca2, 0x2c83, 0x1ce0, 0x0cc1,
  0xef1f, 0xff3e, 0xcf5d, 0xdf7c, 0xaf9b, 0xbfba, 0x8fd9, 0x9ff8,
  0x6e17, 0x7e36, 0x4e55, 0x5e74, 0x2e93, 0x3eb2, 0x0ed1, 0x1ef0
};

// CRC-32 calculation
const uint32_t crc32tab[256] PROGMEM = {
  0x00000000,0x77073096,0xEE0E612C,0x990951BA,0x076DC419,0x706AF48F,0xE963A535,0x9E6495A3,
  0x0EDB8832,0x79DCB8A4,0xE0D5E91E,0x97D2D988,0x09B64C2B,0x7EB17CBD,0xE7B82D07,0x90BF1D91,
  0x1DB71064,0x6AB020F2,0xF3B97148,0x84BE41DE,0x1ADAD47D,0x6DDDE4EB,0xF4D4B551,0x83D385C7,
  0x136C9856,0x646BA8C0,0xFD62F97A,0x8A65C9EC,0x14015C4F,0x63066CD9,0xFA0F3D63,0x8D080DF5,
  0x3B6E20C8,0x4C69105E,0xD56041E4,0xA2677172,0x3C03E4D1,0x4B04D447,0xD20D85FD,0xA50AB56B,
  0x35B5A8FA,0x42B2986C,0xDBBBC9D6,0xACBCF940,0x32D86CE3,0x45DF5C75,0xDCD60DCF,0xABD13D59,
  0x26D930AC,0x51DE003A,0xC8D75180,0xBFD06116,0x21B4F4B5,0x56B3C423,0xCFBA9599,0xB8BDA50F,
  0x2802B89E,0x5F058808,0xC60CD9B2,0xB10BE924,0x2F6F7C87,0x58684C11,0xC1611DAB,0xB6662D3D,
  0x76DC4190,0x01DB7106,0x98D220BC,0xEFD5102A,0x71B18589,0x06B6B51F,0x9FBFE4A5,0xE8B8D433,
  0x7807C9A2,0x0F00F934,0x9609A88E,0xE10E9818,0x7F6A0DBB,0x086D3D2D,0x91646C97,0xE6635C01,
  0x6B6B51F4,0x1C6C6162,0x856530D8,0xF262004E,0x6C0695ED,0x1B01A57B,0x8208F4C1,0xF50FC457,
  0x65B0D9C6,0x12B7E950,0x8BBEB8EA,0xFCB9887C,0x62DD1DDF,0x15DA2D49,0x8CD37CF3,0xFBD44C65,
  0x4DB26158,0x3AB551CE,0xA3BC0074,0xD4BB30E2,0x4ADFA541,0x3DD895D7,0xA4D1C46D,0xD3D6F4FB,
  0x4369E96A,0x346ED9FC,0xAD678846,0xDA60B8D0,0x44042D73,0x33031DE5,0xAA0A4C5F,0xDD0D7CC9,
  0x5005713C,0x270241AA,0xBE0B1010,0xC90C2086,0x5768B525,0x206F85B3,0xB966D409,0xCE61E49F,
  0x5EDEF90E,0x29D9C998,0xB0D09822,0xC7D7A8B4,0x59B33D17,0x2EB40D81,0xB7BD5C3B,0xC0BA6CAD,
  0xEDB88320,0x9ABFB3B6,0x03B6E20C,0x74B1D29A,0xEAD54739,0x9DD277AF,0x04DB2615,0x73DC1683,
  0xE3630B12,0x94643B84,0x0D6D6A3E,0x7A6A5AA8,0xE40ECF0B,0x9309FF9D,0x0A00AE27,0x7D079EB1,
  0xF00F9344,0x8708A3D2,0x1E01F268,0x6906C2FE,0xF762575D,0x806567CB,0x196C3671,0x6E6B06E7,
  0xFED41B76,0x89D32BE0,0x10DA7A5A,0x67DD4ACC,0xF9B9DF6F,0x8EBEEFF9,0x17B7BE43,0x60B08ED5,
  0xD6D6A3E8,0xA1D1937E,0x38D8C2C4,0x4FDFF252,0xD1BB67F1,0xA6BC5767,0x3FB506DD,0x48B2364B,
  0xD80D2BDA,0xAF0A1B4C,0x36034AF6,0x41047A60,0xDF60EFC3,0xA867DF55,0x316E8EEF,0x4669BE79,
  0xCB61B38C,0xBC66831A,0x256FD2A0,0x5268E236,0xCC0C7795,0xBB0B4703,0x220216B9,0x5505262F,
  0xC5BA3BBE,0xB2BD0B28,0x2BB45A92,0x5CB36A04,0xC2D7FFA7,0xB5D0CF31,0x2CD99E8B,0x5BDEAE1D,
  0x9B64C2B0,0xEC63F226,0x756AA39C,0x026D930A,0x9C0906A9,0xEB0E363F,0x72076785,0x05005713,
  0x95BF4A82,0xE2B87A14,0x7BB12BAE,0x0CB61B38,0x92D28E9B,0xE5D5BE0D,0x7CDCEFB7,0x0BDBDF21,
  0x86D3D2D4,0xF1D4E242,0x68DDB3F8,0x1FDA836E,0x81BE16CD,0xF6B9265B,0x6FB077E1,0x18B74777,
  0x88085AE6,0xFF0F6A70,0x66063BCA,0x11010B5C,0x8F659EFF,0xF862AE69,0x616BFFD3,0x166CCF45,
  0xA00AE278,0xD70DD2EE,0x4E048354,0x3903B3C2,0xA7672661,0xD06016F7,0x4969474D,0x3E6E77DB,
  0xAED16A4A,0xD9D65ADC,0x40DF0B66,0x37D83BF0,0xA9BCAE53,0xDEBB9EC5,0x47B2CF7F,0x30B5FFE9,
  0xBDBDF21C,0xCABAC28A,0x53B39330,0x24B4A3A6,0xBAD03605,0xCDD70693,0x54DE5729,0x23D967BF,
  0xB3667A2E,0xC4614AB8,0x5D681B02,0x2A6F2B94,0xB40BBE37,0xC30C8EA1,0x5A05DF1B,0x2D02EF8D
};


// Global variables
String build = "v3.10";
String cmd = "";              // Gather a new AT command to this string from serial
bool cmdMode = true;          // Are we in AT command mode or connected mode
bool callConnected = false;   // Are we currently in a call
bool telnet = false;          // Is telnet control code handling enabled
bool verboseResults = false;
//#define DEBUG 1             // Print additional debug information to serial channel
#undef DEBUG
#define LISTEN_PORT 23        // Listen to this if not connected. Set to zero to disable.
int tcpServerPort = LISTEN_PORT;
#define RING_INTERVAL 3000    // How often to print RING when having a new incoming connection (ms)
unsigned long lastRingMs = 0; // Time of last "RING" message (millis())
//long myBps;                 // What is the current BPS setting
#define MAX_CMD_LENGTH 256    // Maximum length for AT command
char plusCount = 0;           // Go to AT mode at "+++" sequence, that has to be counted
unsigned long plusTime = 0;   // When did we last receive a "+++" sequence
#define LED_TIME 15           // How many ms to keep LED on at activity
unsigned long ledTime = 0;
#define TX_BUF_SIZE 256       // Buffer where to read from serial before writing to TCP
// (that direction is very blocking by the ESP TCP stack,
// so we can't do one byte a time.)
uint8_t txBuf[TX_BUF_SIZE];
extern const int speedDialAddresses[] = { DIAL0_ADDRESS, DIAL1_ADDRESS, DIAL2_ADDRESS, DIAL3_ADDRESS, DIAL4_ADDRESS, DIAL5_ADDRESS, DIAL6_ADDRESS, DIAL7_ADDRESS, DIAL8_ADDRESS, DIAL9_ADDRESS };
String speedDials[10];

byte serialConfig;
extern const int bits[] = { SERIAL_5N1, SERIAL_6N1, SERIAL_7N1, SERIAL_8N1, SERIAL_5N2, SERIAL_6N2, SERIAL_7N2, SERIAL_8N2, SERIAL_5E1, SERIAL_6E1, SERIAL_7E1, SERIAL_8E1, SERIAL_5E2, SERIAL_6E2, SERIAL_7E2, SERIAL_8E2, SERIAL_5O1, SERIAL_6O1, SERIAL_7O1, SERIAL_8O1, SERIAL_5O2, SERIAL_6O2, SERIAL_7O2, SERIAL_8O2 };
String bitsDisp[] = { "5-N-1", "6-N-1", "7-N-1", "8-N-1 (default)", "5-N-2", "6-N-2", "7-N-2", "8-N-2", "5-E-1", "6-E-1", "7-E-1", "8-E-1", "5-E-2", "6-E-2", "7-E-2", "8-E-2", "5-O-1", "6-O-1", "7-O-1", "8-O-1", "5-O-2", "6-O-2", "7-O-2", "8-O-2" };

extern const int bauds[] = { 300, 1200, 2400, 4800, 9600, 19200, 38400, 57600, 115200 };
String baudDisp[] = { "300", "1200", "2400", "4800", "9600", "19.2k", "38.4k", "57.6k", "115k" };
byte serialSpeed;

String mainMenuDisp[] = { "MODEM Mode", "File Transfer", "Text Playback", "PPP Gateway", "SLIP Gateway", "Utilities", "Config" };
String settingsMenuDisp[] = { "MAIN", "WiFi Setup", "Baud Rate", "Serial Config", "Orientation", "Default Menu", "USB Debug", "Factory Reset", "Reboot", "About" };
String orientationMenuDisp[] = { "Normal", "Flipped" };
String playbackMenuDisp[] = { "MAIN", "List Files", "Display File", "Playback File", "Evaluate Key", "Terminal Mode" };
String fileMenuDisp[] = { "MAIN", "List Files on SD", "Send (from SD)", "Recieve (to SD)" };
String protocolMenuDisp[] = { "BACK", "Raw", "XModem", "YModem", "ZModem" }; //, "Kermit" };
String defaultModeDisp[] = { "Main Menu", "MODEM Mode" };
String diagnosticsMenuDisp[] = { "BACK", "Auto-Detect Baud", "Hex Dump Mode", "Loopback Test", "Signal Monitor", "Information" };

bool echo = true;
bool autoAnswer = false;
bool quietMode = false;        // ATQ1 suppresses result codes
byte escChar = '+';            // ATS2 escape character (255=disabled)
String ssid, password, busyMsg;
byte ringCount = 0;
String resultCodes[] = { "OK", "CONNECT", "RING", "NO CARRIER", "ERROR", "", "NO DIALTONE", "BUSY", "NO ANSWER" };
enum resultCodes_t { R_OK_STAT, R_CONNECT, R_RING, R_NOCARRIER, R_ERROR, R_NONE, R_NODIALTONE, R_BUSY, R_NOANSWER };
unsigned long connectTime = 0;
bool petTranslate = false; // Fix PET MCTerm 1.26C Pet->ASCII encoding to actual ASCII
bool consoleMode = true;   // AT&C: First telnet connection becomes console (true) or all connections ring (false)
bool signalMonitorEnabled = false; // Show signal states on OLED in modem mode
bool bHex = false;
enum flowControl_t { F_NONE, F_HARDWARE, F_SOFTWARE };
byte flowControl = F_NONE;      // Use flow control
bool txPaused = false;          // Has flow control asked us to pause?
enum pinPolarity_t { P_INVERTED, P_NORMAL }; // Is LOW (0) or HIGH (1) active?
byte pinPolarity = P_INVERTED;
byte dtrMode = 0;                // DTR handling: 0=ignore, 1=cmd mode, 2=hang up
enum dispOrientation_t { D_NORMAL, D_FLIPPED }; // Normal or Flipped
byte dispOrientation = D_NORMAL;
enum defaultMode_t { D_MAINMENU, D_MODEMMENU }; // Main or Modem
byte defaultMode = D_MAINMENU;
bool usbDebug = true;  // Enable USB serial debug output (default: enabled)

int menuMode = MODE_MAIN;
int xferMode = XFER_SEND;
int lastMenu = -1;
int menuCnt = 0;
int menuIdx = 0;
int dispCharCnt = 0;
int dispLineCnt = 0;
int dispAnsiCnt = 0;
unsigned long xferBytes = 0;
unsigned int xferBlock = 0;
String xferMsg = "";
unsigned long bytesSent = 0;
unsigned long bytesRecv = 0;
bool sentChanged = false;
bool recvChanged = false;
bool speedDialShown = false;

//file transfer related variables
const int chipSelect = 5; //D8
byte packetNumber=0;  //which packet number we're on - YMODEM starts with 0 which contains file name and size.
int blockSize = 1024;
int packetSize = 1029;
bool lastPacket = false; //did i just send the last packet? if so, next thing to send is EOT
int eotSent = 0; //did i send the EOT? if so, wait for ACK
bool finalFileSent = false;
bool readyToReceive = false;
int fileIndex = 0; //used to keep track of what file we're on for batch transfers
bool zeroPacket = true;
File logFile;
File xferFile;
bool EscapeTelnet = false;
CRC16 crc;
auto timer = timer_create_default();
Timer<16> modem_timer = timer_create_default();
String terminalMode = "VT100";
String fileName = "";
String files[100];
String waitTime;
bool msgFlag=false;
bool BTNUP=false;
bool BTNDN=false;
bool BTNEN=false;
bool BTNBK=false;

extern const uint8_t PROGMEM wifi_symbol[] = {
  0b00111100,
  0b01000010,
  0b10011001,
  0b00100100,
  0b01000010,
  0b00011000,
  0b00100100
};

extern const uint8_t PROGMEM phon_symbol[] = {
  0b00111100,
  0b11000011,
  0b11011011,
  0b00111100,
  0b01111110,
  0b01111110,
  0b01111110,
  0b01111110
};

// Telnet codes
#define DO 0xfd
#define WONT 0xfc
#define WILL 0xfb
#define DONT 0xfe

WiFiClient tcpClient;
WiFiClient consoleClient;                 // Telnet console client (separate from call client)
bool consoleConnected = false;            // Telnet console is connected
WiFiServer tcpServer(LISTEN_PORT);        // port will be set via .begin(port)
WebServer webServer(80);
MDNSResponder mdns;
HardwareSerial PhysicalSerial(2);

// Serial I/O functions moved to src/modules/serial_io.cpp
// Settings functions moved to src/modules/settings.cpp
// Network functions moved to src/modules/network.cpp

// Forward declarations for functions still in main.cpp
void showMessage(String message);
void modemMenuMsg();
void modemConnected();
void firmwareCheck();
void firmwareUpdate();
void firmwareUpdateStarted();
void firmwareUpdateFinished();
void firmwareUpdateProgress(int cur, int total);
void firmwareUpdateError(int err);
void enterModemMode();
void mainLoop();
void modemLoop();
void fileLoop();
void playbackLoop();
void settingsLoop();
void baudLoop();
void serialLoop();
void listFilesLoop();
void orientationLoop();
void defaultModeLoop();
void protocolLoop();
void showMenu(String menuName, String options[], int sz, int dispMode, int defaultSel);
void menuOption(int idx, String item);
void fileMenu(bool arrow);
void playbackMenu(bool arrow);
void settingsMenu(bool arrow);
void baudMenu(bool arrow);
void serialMenu(bool arrow);
void orientationMenu(bool arrow);
void defaultModeMenu(bool arrow);
void listFilesMenu(bool arrow);
void listFiles();
String getLine();
void clearInputBuffer();
bool checkCancel();
void resetGlobals();
String getFileSize(String fileName);
void sendFileRaw();
void receiveFileRaw();
void sendFileXMODEM();
void receiveFileXMODEM();
void sendFileYMODEM();
void receiveFileYMODEM();
void sendLoopXMODEM(File dataFile, String fileName, String fileSize);
void sendLoopYMODEM(File dataFile, String fileName, String fileSize);
void sendPacket(File dataFile);
void sendZeroPacket(String fileName, String fileSize);
void sendFinalPacket();
void sendTelnet(uint8_t* p, int len);
void receiveLoopXMODEM();
void receiveLoopYMODEM();
void changeTerminalMode();
void evalKey();
char getKey();
void waitKey(int k1, int k2);
bool displayFile(String fileName, bool playback, int startPos);
void displayChar(char c, int direction);
void addLog(String s);
bool refreshDisplay(void* argument);
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
void loop()
{
  if (menuMode==MODE_MAIN)
    mainLoop();
  else if (menuMode==MODE_MODEM)
    modemLoop();
  else if (menuMode==MODE_FILE)
    fileLoop();
  else if (menuMode==MODE_PLAYBACK)
    playbackLoop();
  else if (menuMode==MODE_SETTINGS)
    settingsLoop();
  else if (menuMode==MODE_SETBAUD)
    baudLoop();    
  else if (menuMode==MODE_SERIALCONFIG)
    serialLoop();    
  else if (menuMode==MODE_LISTFILE)
    listFilesLoop();
  else if (menuMode==MODE_ORIENTATION)
    orientationLoop();
  else if (menuMode==MODE_DEFAULTMODE)
    defaultModeLoop();
  else if (menuMode==MODE_PROTOCOL)
    protocolLoop();
  else if (menuMode==MODE_SLIP)
    slipLoop();
  else if (menuMode==MODE_PPP)
    pppLoop();
  else if (menuMode==MODE_WIFI_SETUP)
    wifiSetupLoop();
  else if (menuMode==MODE_WIFI_PASSWORD)
    wifiPasswordLoop();
  else if (menuMode==MODE_DIAGNOSTICS)
    diagnosticsLoop();
}

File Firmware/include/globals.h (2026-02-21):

#ifndef GLOBALS_H
#define GLOBALS_H

#include <Arduino.h>
#include <WiFi.h>
#include <WiFiClient.h>
#include <WebServer.h>
#include <ESPmDNS.h>
#include <HardwareSerial.h>
#include <Adafruit_SSD1306.h>
#include "SD.h"
#include "arduino-timer.h"

// Debug flags - uncomment to enable verbose debug output
#define PPP_DEBUG    // Enable PPP/LCP/IPCP debug output on Serial

// Pin definitions
#define SWITCH_PIN 0       // GPIO0 (programming mode pin)
#define LED_PIN 2          // Status LED

#define DCD_PIN 33         // DCD Carrier Status
#define RTS_PIN 15         // RTS Request to Send
#define CTS_PIN 27         // CTS Clear to Send
#define DTR_PIN 4          // DTR Data Terminal Ready
#define DSR_PIN 26         // DSR Data Set Ready
#define RI_PIN  25         // RI Ring Indicator

#define SW1_PIN 36         // DOWN
#define SW2_PIN 39         // BACK
#define SW3_PIN 34         // ENTER
#define SW4_PIN 35         // UP

// SD Card Pins
#define SD_CS 5
#define SPI_MOSI 23
#define SPI_MISO 19
#define SPI_SCK 18

#define RXD2 16
#define TXD2 17

// Mode definitions
#define MODE_MAIN 0
#define MODE_MODEM 1
#define MODE_FILE 2
#define MODE_PLAYBACK 3
#define MODE_SETTINGS 4
#define MODE_SETBAUD 5
#define MODE_LISTFILE 6
#define MODE_ORIENTATION 7
#define MODE_DEFAULTMODE 8
#define MODE_PROTOCOL 9
#define MODE_SERIALCONFIG 10
#define MODE_SLIP 11
#define MODE_PPP 12
#define MODE_WIFI_SETUP 13
#define MODE_WIFI_PASSWORD 14
#define MODE_DIAGNOSTICS 15

// Menu modes
#define MENU_BOTH 0
#define MENU_NUM  1
#define MENU_DISP 2

// Transfer modes
#define XFER_SEND 0
#define XFER_RECV 1

// Display settings
#define SCREEN_WIDTH 128
#define SCREEN_HEIGHT 64
#define OLED_RESET -1
#define SCREEN_ADDRESS 0x3C

// EEPROM addresses
#define VERSION_ADDRESS 0
#define VERSION_LEN     2
#define SSID_ADDRESS    2
#define SSID_LEN        32
#define PASS_ADDRESS    34
#define PASS_LEN        63
#define IP_TYPE_ADDRESS 97
#define STATIC_IP_ADDRESS 98
#define STATIC_GW       102
#define STATIC_DNS      106
#define STATIC_MASK     110
#define BAUD_ADDRESS    111
#define ECHO_ADDRESS    112
#define SERVER_PORT_ADDRESS 113
#define AUTO_ANSWER_ADDRESS 115
#define TELNET_ADDRESS  116
#define VERBOSE_ADDRESS 117
#define PET_TRANSLATE_ADDRESS 118
#define FLOW_CONTROL_ADDRESS 119
#define PIN_POLARITY_ADDRESS 120
#define DTR_MODE_ADDRESS 121
#define DIAL0_ADDRESS   200
#define DIAL1_ADDRESS   250
#define DIAL2_ADDRESS   300
#define DIAL3_ADDRESS   350
#define DIAL4_ADDRESS   400
#define DIAL5_ADDRESS   450
#define DIAL6_ADDRESS   500
#define DIAL7_ADDRESS   550
#define DIAL8_ADDRESS   600
#define DIAL9_ADDRESS   650
#define BUSY_MSG_ADDRESS 700
#define BUSY_MSG_LEN    80
#define ORIENTATION_ADDRESS 780
#define DEFAULTMODE_ADDRESS 790
#define SERIALCONFIG_ADDRESS 791
#define USB_DEBUG_ADDRESS 792
#define QUIET_MODE_ADDRESS 793
#define ESC_CHAR_ADDRESS 794
#define CONSOLE_MODE_ADDRESS 795
#define SIGNAL_MONITOR_ADDRESS 796

// Port Forwarding (generic, shared by SLIP and PPP)
#define PORTFWD_BASE    950   // Port forwards start here
#define PORTFWD_SIZE    10    // 10 bytes per entry (active, proto, extPort, intPort, intIP)
#define PORTFWD_COUNT   8     // Max 8 port forwards
// Total: 950 + (8 * 10) = 1030

#define LAST_ADDRESS    1030  // Extended for port forwards

// Version
#define VERSIONA 0
#define VERSIONB 1

// Modem constants
#define LISTEN_PORT 23
#define RING_INTERVAL 3000
#define MAX_CMD_LENGTH 256
#define LED_TIME 15
#define TX_BUF_SIZE 256

// ============================================================================
// ZMODEM Protocol Constants (per official spec and modern implementations)
// ============================================================================

// Frame types (complete set)
#define ZRQINIT     0x00  // Request receive init (sender to receiver)
#define ZRINIT      0x01  // Receive init (receiver to sender)
#define ZSINIT      0x02  // Send init sequence (optional)
#define ZACK        0x03  // Acknowledge
#define ZFILE       0x04  // File name from sender
#define ZSKIP       0x05  // Skip this file
#define ZNAK        0x06  // Last packet was garbled
#define ZABORT      0x07  // Abort batch transfers
#define ZFIN        0x08  // Finish session
#define ZRPOS       0x09  // Resume data at this position
#define ZDATA       0x0A  // Data packet(s) follow
#define ZEOF        0x0B  // End of file
#define ZFERR       0x0C  // Fatal read/write error
#define ZCRC        0x0D  // Request/response for file CRC
#define ZCHALLENGE  0x0E  // Security challenge
#define ZCOMPL      0x0F  // Request is complete
#define ZCAN        0x10  // Other end cancelled with CAN chars
#define ZFREECNT    0x11  // Request free bytes on filesystem
#define ZCOMMAND    0x12  // Command from sending program
#define ZSTDERR     0x13  // Output to stderr

// Header format indicators
#define ZPAD        0x2A  // '*' Padding char (begins frames)
#define ZDLE        0x18  // Ctrl-X ZModem escape
#define ZDLEE       0x58  // Escaped ZDLE (ZDLE XOR 0x40)
#define ZBIN        0x41  // 'A' Binary frame (CRC-16)
#define ZHEX        0x42  // 'B' Hex frame (CRC-16)
#define ZBIN32      0x43  // 'C' Binary frame (CRC-32)

// Data subpacket terminators (frame end types)
#define ZCRCE       0x68  // 'h' CRC next, end frame, header follows
#define ZCRCG       0x69  // 'i' CRC next, frame continues nonstop
#define ZCRCQ       0x6A  // 'j' CRC next, frame continues, ZACK expected
#define ZCRCW       0x6B  // 'k' CRC next, end frame, ZACK expected

// Special ZDLE sequences
#define ZRUB0       0x6C  // Translate to 0x7F (DEL)
#define ZRUB1       0x6D  // Translate to 0xFF

// ZRINIT capability flags (ZF0)
#define ZF0_CANFDX  0x01  // Can send/receive true full duplex
#define ZF0_CANOVIO 0x02  // Can receive during disk I/O
#define ZF0_CANBRK  0x04  // Can send break signal
#define ZF0_CANCRY  0x08  // Can decrypt (not used)
#define ZF0_CANLZW  0x10  // Can uncompress (not used)
#define ZF0_CANFC32 0x20  // Can use 32-bit CRC
#define ZF0_ESCCTL  0x40  // Expects ctrl chars escaped
#define ZF0_ESC8    0x80  // Expects 8th bit escaped

// Byte positions in header array
#define ZF0         4     // First flags byte (also ZP3 for positions)
#define ZF1         3     // Second flags byte (also ZP2)
#define ZF2         2     // Third flags byte (also ZP1)
#define ZF3         1     // Fourth flags byte (also ZP0)
#define ZP0         1     // Low order position byte
#define ZP1         2
#define ZP2         3
#define ZP3         4     // High order position byte

// Control characters
#define CAN         0x18  // Cancel character
#define XON         0x11  // Resume transmission
#define XOFF        0x13  // Pause transmission
#define DLE         0x10  // Data Link Escape
#define CR          0x0D  // Carriage return
#define LF          0x0A  // Line feed
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

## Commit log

2022-06-27 Add kit assembly instructions
2022-11-01 v2 enclosure update
    Updated enclosure includes display opening on cover and openings for buttons
    [WiRSa Enclosure.scad, WiRSa Enclosure.stl]
2022-11-01 v2 PCB update
    [WiRSa-B_Cu.gbr, WiRSa-B_Mask.gbr, WiRSa-B_Silkscreen.gbr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]
2022-11-01 v2 assembly instructions update
2022-11-01 pictures of the v2 revision assembly & enclosure
2022-12-04 added WiRSa firmware version check after wifi connects
2023-07-29 some improvements to enclosure
    Thicker walls, a slightly taller and some small adjustments to the cover to make it easier get on and slide. Overall the PCB fits better now and the enclosure should be more durable.
    [WiRSa Enclosure.scad, WiRSa Enclosure.stl]
2023-11-11 Increases height of enclosure slightly
    [WiRSa Enclosure.scad, WiRSa Enclosure.stl]
2024-12-09 WiRSa v3.01
    Initial push for the version 3 design
    [WiRSa Enclosure V3.scad, WiRSa Enclosure V3.stl, WiRSa Enclosure.scad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]
2024-12-29 V3 Enclosure
    [WiRSa Enclosure V3 No Battery.stl, WiRSa Enclosure V3 With Battery.stl, WiRSa Enclosure V3.scad]
2025-01-02 WiRSa v3.02
    Fixed reboot function for ESP32 device
2025-01-22 V3 R1
    [WiRSa Enclosure V3 No Battery.stl, WiRSa Enclosure V3 Switch Only.stl, WiRSa Enclosure V3 With Battery.stl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]
2026-01-08 WiRSa v3.03
    - refactored code, using platform.io now instead of Arduino IDE
    - fixed SD card R/W issue
    - fixed IP display (ATI etc)
    - added ZModem support
    - fix OTA update
    [display_menu.cpp, firmware.cpp, globals.h]
2026-01-23 WiRSa v3.04
    added PPP mode
2026-01-26 Revise README for WiRSa v3 with detailed features
    Expanded the README to include detailed features, usage instructions, and hardware specifications for the WiRSa v3.
2026-01-26 Revise README for WiRSa v3
    Updated project description to clarify functionality and features.
2026-01-27 WiRSa v3.05
    added SLIP mode, improved web config interface
    [display_menu.cpp, main.cpp, modem.cpp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]
2026-01-31 WiRSa v3.06
    added port forwarding to SLIP/PPP modes
    [globals.h, main.cpp, modem.cpp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]
2026-01-31 WiRSa v3.06
2026-02-10 WiRSa v3.07
    SLIP/PPP modes bug fixes for linux compatibility (slattach, pppd)
    [main.cpp, ppp.cpp, ppp_mode.cpp]
2026-02-17 WiRSa v3.08
    - fixed wifi password entry via screen/buttons
    - implemented AT&D0-3 (DTR control)
    - DSR and RI pins now driven as outputs per RS-232 standard
    [globals.h, main.cpp, modem.cpp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]
2026-02-19 WiRSa v3.09
    - when S0=1 (auto-answer) telnet goes to RING/CONNECT/DCD
    - added ATQ0/ATQ1 and ATS2=N commands
2026-02-20 enclosure fix
    - fixed the reversed up/down arrows
    - added some individual STLs for printing individual parts
    [WiRSa Enclosure V3 Base Only NB.stl, WiRSa Enclosure V3 Base Only WB.stl, WiRSa Enclosure V3 Battery Only.stl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]
2026-02-21 WiRSa v3.10
    - modified signal monitor to show on screen while in modem mode
    - fixed telnet call mode to assert DCD
    - fixed some pin polarity issues
    [diagnostics.cpp, display_menu.cpp, globals.h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]
